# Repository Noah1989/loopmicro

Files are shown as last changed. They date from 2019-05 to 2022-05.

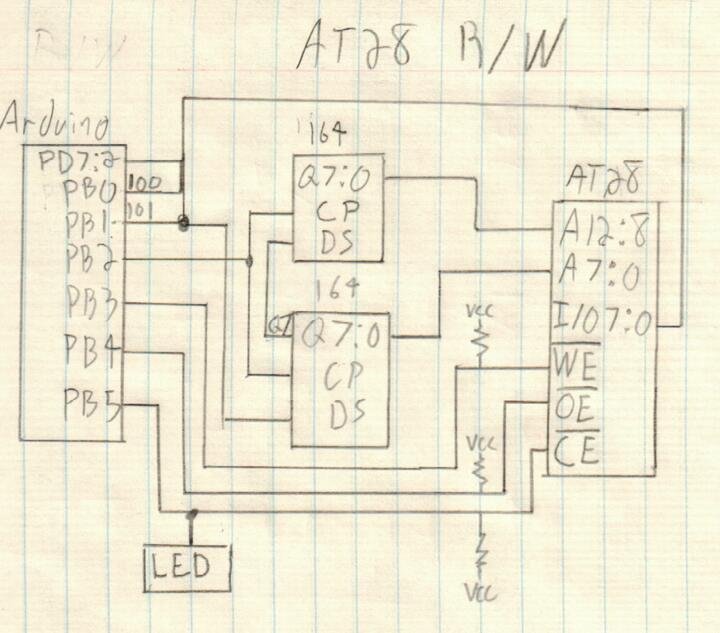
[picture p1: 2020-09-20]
software/collapseos/doc/hw/arduinouno/img/at28wr.jpg

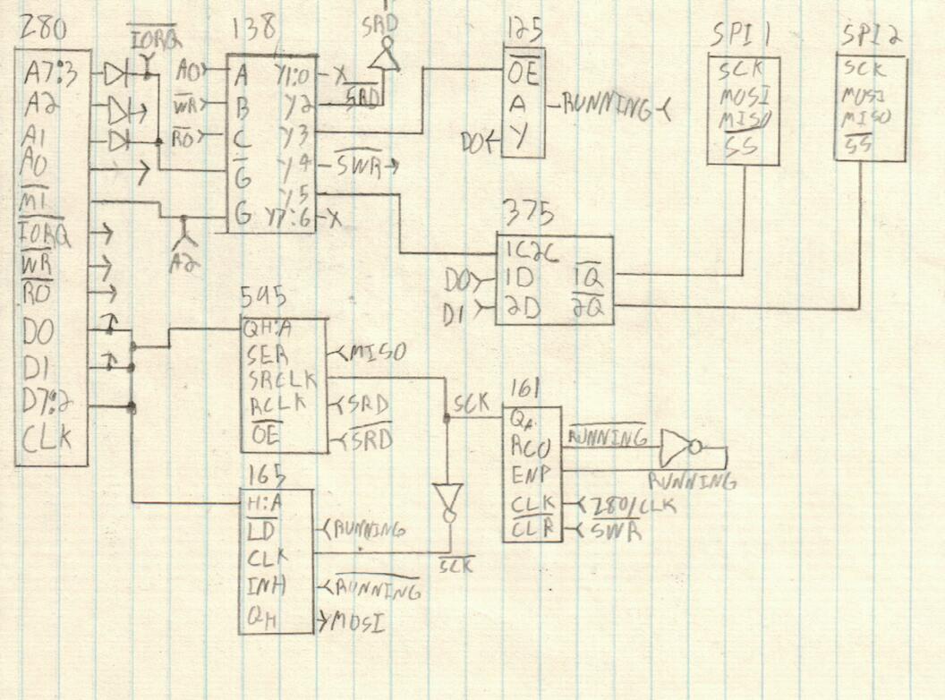
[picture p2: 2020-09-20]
software/collapseos/doc/hw/z80/img/spirelay.jpg

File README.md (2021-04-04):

# Loop Microcomputer
a minmal 8-bit machine that is...

- ... independent:
    - contains all the tools required to design another version of itself
    - does not require high soldering skills, uses through-hole parts only
    - uses only "evergreen" parts that have been in production for decades and are still made today

- ... aproachable:
    - simple through reduction
    - NO hidden complexity behind brittle abstractions
    - open source and self-documenting

- ... powerful, with it you can:
    - learn/teach how computers work
    - design electronics
    - control CNC machines / 3d printers
    - play games

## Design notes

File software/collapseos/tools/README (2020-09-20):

# Tools

This folder contains tools to communicate to Collapse OS machines from a modern
environment or to manipulate a blkfs. 

Communication tools all take a device path as a first argument. That device is
the serial device that connects you to your machine. It's often a USB-to-TTL
dongle. When `-` is specified, `stdin` is used as the device.

Note that for these tools to work well, you need the serial device to be
properly set up, TTY-wise. You'll probably want to do that with `stty`. The
recommended settings are "raw crtscts". Here's an example working on OpenBSD:

    $ ( stty 115200 raw crtscts ; ./upload - a000 os.bin ) <> /dev/cuaU0

To be honest, I'm having a bit of troubles making these tools work as well on
OpenBSD as they do in Linux. But it *does* work. Here are some advices:

* Use `cuaXX` instead of `ttyXX`.
* Run `cu -l /dev/cuaXX` before running your tool and run a dummy command to
  make sure that the output buffer is flushed.
* Use the "raw" option to avoid TTY-processing options to mess with data.
* If you experience random failures in your command, try inserting a "sleep 2"
  between your "stty" invocation and the command. In my experience, these tend
  to help.

On Linux, it's generally easier:

* Run screen on the device (often `/dev/ttyUSBX`)
* Quit with `CTRL+A :quit`
* Run the tool on the same device

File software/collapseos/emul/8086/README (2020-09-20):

# 8086 emulator

This folder contains emulator for 8086 binaries of Collapse OS. The bulk of
it is a fork of Fake86 by Mike Chambers.

`forth` is an imaginary hardware used for userspace development and testing.
This machine has an imaginary interrupt API and does not conform to PC/AT.

`pcat` is a very simple PC/AT emulator. The BIOS interrupt hooks implemented in
it only cover Collapse OS' own needs.

## Requirements

You need `curses` to build the `forth` executable.

## Build

Run `make` and it builds the `forth` and `pcat` interpreters.

## Usage

The `./forth` executable here works like the one in `/cvm`, except that it runs
under an emulated 8086 machine instead of running natively. Refer to
`/cvm/README` for details.

`pcat` needs to be suppied a path to a floppy disk image with a proper MBR.
`disk.bin` provided by the `pcat` recipe is sufficient.

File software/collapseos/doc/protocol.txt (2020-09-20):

# Protocols

Some subsystems (and in the case of KEY and EMIT, the core) re-
quire drivers to implement certain words in a certain way. For
example, the core requires drivers to implement (key?) and
(emit) or else it won't know how to provide a console.

These protocols are described here.

# TTY protocol

(key?)     -- c? f Returns whether a key has been pressed and,
                   if it has, returns which key. When f is
                   false, c is *not* placed in the stack.
(emit)     c --    Spit a character on the console.

# PS/2 protocol

This protocol enables communication with a device that spits
PS/2 keycodes.

(ps2kc)   -- kc    Returns the next typed PS/2 keycode from the
                   console. 0 if nothing was typed.

# SPI Relay protocol

This protocol enables communication with a SPI relay. This
protocol is designed to support devices with multiple endpoints.
To that end, (spie) takes a device ID argument, with a meaning
that is up to the device itself. To disable all devices, supply
0 to (spie).

We expect relay devices to support only one enabled device at
once. Enabling a specific device is expected to disable the
previously enabled one.

(spie)    n --     Enable SPI device
(spix)    n -- n   Perform SPI exchange (push a number, get a
                   number back)
                  
# Grid protocol

See grid.txt

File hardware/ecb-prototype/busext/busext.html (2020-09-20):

# /home/stefan/micro-21/hardware/ecb-prototype/busext/busext.sch

Sat May 8 12:38:23 2021

Eeschema 5.1.9

Component Count:13

Ref | Qnty | Value | Part | Footprint | Description | Vendor
C1, C2, C3, C4 | 4 | 100nF | Device:C_Small | Capacitor_THT:C_Rect_L7.2mm_W2.5mm_P5.00mm_FKS2_FKP2_MKS2_MKP2 | Unpolarized capacitor, small symbol
C5 | 1 | CP | Device:CP | Capacitor_THT:CP_Radial_D5.0mm_P2.00mm | Polarized capacitor
D1 | 1 | BAT46 | Device:D_Small_ALT | Diode_THT:D_DO-35_SOD27_P7.62mm_Horizontal | Diode, small symbol, filled shape
J1, J2 | 2 | C96ABC | Connector:C96ABC | Connector_DIN:DIN41612_C_3x32_Male_Horizontal_THT | Connector Europe, 96 contacts, ranges A,B,C
R1 | 1 | 10k | Device:R | Resistor_THT:R_Axial_DIN0207_L6.3mm_D2.5mm_P10.16mm_Horizontal | Resistor
U1, U2, U3 | 3 | 74HC244 | 74xx:74HC244 | Package_DIP:DIP-20_W7.62mm_Socket_LongPads | 8-bit Buffer/Line Driver 3-state
U4 | 1 | 74HC245 | 74xx:74HC245 | Package_DIP:DIP-20_W7.62mm_Socket_LongPads | Octal BUS Transceivers, 3-State outputs

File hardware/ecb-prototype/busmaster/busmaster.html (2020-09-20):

# /home/stefan/micro-21/hardware/ecb-prototype/busmaster/busmaster.sch

Sat May 8 12:36:06 2021

Eeschema 5.1.9

Component Count:33

Ref | Qnty | Value | Part | Footprint | Description | Vendor
C1, C2, C3, C4, C5, C6, C7, C8, C9, C10, C11, C12 | 12 | 100nF | Device:C_Small | Capacitor_THT:C_Rect_L7.2mm_W2.5mm_P5.00mm_FKS2_FKP2_MKS2_MKP2 | Unpolarized capacitor, small symbol
C13 | 1 | CP | Device:CP | Capacitor_THT:CP_Radial_D5.0mm_P2.00mm | Polarized capacitor
D1 | 1 | BAT46 | Device:D_Small_ALT | Diode_THT:D_DO-35_SOD27_P7.62mm_Horizontal | Diode, small symbol, filled shape
J1, J2 | 2 | C96ABC | Connector:C96ABC | Connector_DIN:DIN41612_C_3x32_Male_Horizontal_THT | Connector Europe, 96 contacts, ranges A,B,C
R1, R2, R3, R4 | 4 | R | Device:R | Resistor_THT:R_Axial_DIN0207_L6.3mm_D2.5mm_P10.16mm_Horizontal | Resistor
SW1 | 1 | SW_Coded_SH-7050 | Switch:SW_Coded_SH-7050 | Button_Switch_THT:Nidec_Copal_SH-7010C | Rotary switch, 4-bit encoding, 16 positions, Real code
U1 | 1 | 74HC688 | 74xx:74HC688 | Package_DIP:DIP-20_W7.62mm_Socket_LongPads | 8-bit magnitude comparator
U2 | 1 | 74HC138 | 74xx:74LS138 | Package_DIP:DIP-16_W7.62mm_Socket_LongPads | Decoder 3 to 8 active low outputs
U3 | 1 | 74HC00 | 74xx:7400 | Package_DIP:DIP-14_W7.62mm_Socket_LongPads | quad 2-input NAND gate
U4 | 1 | 74HC573 | 74xx:74LS573 | Package_DIP:DIP-20_W7.62mm_Socket_LongPads | 8-bit Latch 3-state outputs
U5, U10, U11 | 3 | 74HC244 | 74xx:74HC244 | Package_DIP:DIP-20_W7.62mm_Socket_LongPads | 8-bit Buffer/Line Driver 3-state
U6, U7, U8, U9 | 4 | 74HC161 | 74xx:74LS161 | Package_DIP:DIP-16_W7.62mm_Socket_LongPads | Synchronous 4-bit programmable binary Counter
U12 | 1 | 74HC245 | 74xx:74HC245 | Package_DIP:DIP-20_W7.62mm_Socket_LongPads | Octal BUS Transceivers, 3-State outputs

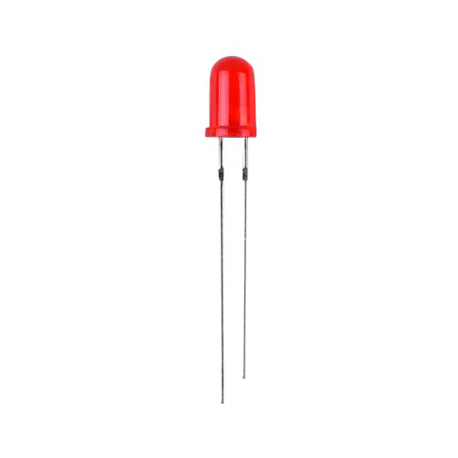
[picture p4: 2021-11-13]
emulator/assets/led.png

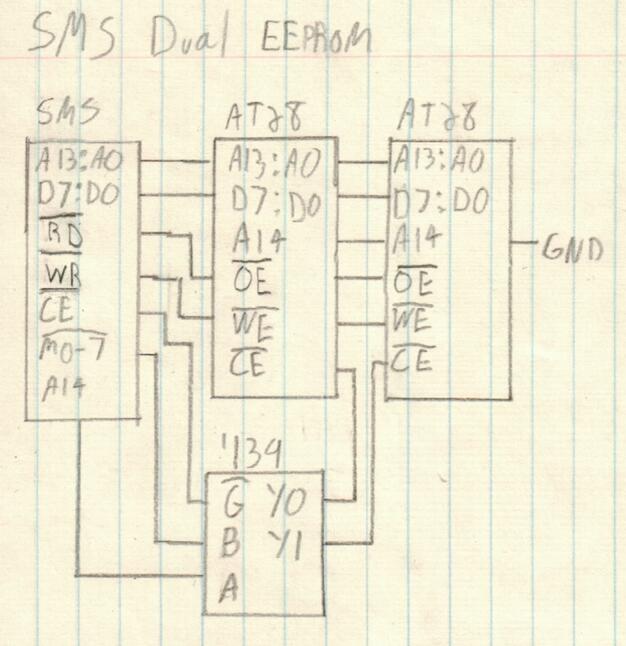
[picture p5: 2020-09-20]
software/collapseos/doc/hw/z80/sms/img/dual-at28.jpg

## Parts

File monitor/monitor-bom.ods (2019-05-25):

Designator | Package | Quantity | Designation
C2 | C_Rect_L7.2mm_W3.0mm_P5.00mm_FKS2_FKP2_MKS2_MKP2 | 1 | 0.1µF
C1 | CP_Radial_D5.0mm_P2.00mm | 1 | 1µF
D1,D2 | D_DO-35_SOD27_P7.62mm_Horizontal | 2 | DIODE
U1,U5 | DIP-14_W7.62mm_Socket_LongPads | 2 | 74HC4075
U3,U4 | DIP-14_W7.62mm_Socket_LongPads | 2 | 74HC00
U11 | DIP-14_W7.62mm_Socket_LongPads | 1 | 74HC08
U12 | DIP-14_W7.62mm_Socket_LongPads | 1 | 74HC86
U13 | DIP-14_W7.62mm_Socket_LongPads | 1 | 74HC74
U26,U27,U28,U29 | DIP-14_W7.62mm_Socket_LongPads | 4 | 74HC14
U2 | DIP-16_W7.62mm_Socket_LongPads | 1 | 74AC138
U8,U9,U10 | DIP-16_W7.62mm_Socket_LongPads | 3 | 74HC148
U6,U7 | DIP-20_W7.62mm_Socket_LongPads | 2 | 74AC574
U14,U16,U18,U20,U22,U24 | DIP-20_W7.62mm_Socket_LongPads | 6 | 74AC573
RN1,RN2,RN3 | R_Array_SIP9 | 3 | 220kΩ
R1 – R48 | R_Axial_DIN0204_L3.6mm_D1.6mm_P5.08mm_Horizontal | 48 | 220Ω
U15,U17,U19,U21,U23,U25 | SC39-11 | 6 | SC39-11
CN1,CN2,CN3 | SIP9_Housing | 3 | 0.1µF
J1 | Socket_DIN41612-CaseC1-full-Male-96Pin-3rows | 1 | C96ABC
SW1 – SW24 | SW_PUSH_6mm_h5mm | 24 | SW

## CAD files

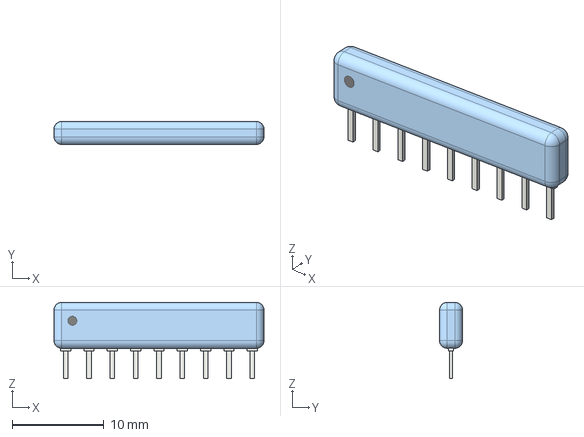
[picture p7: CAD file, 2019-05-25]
monitor/SIP9.STEP
22.9 x 2.51 x 8.30 mm

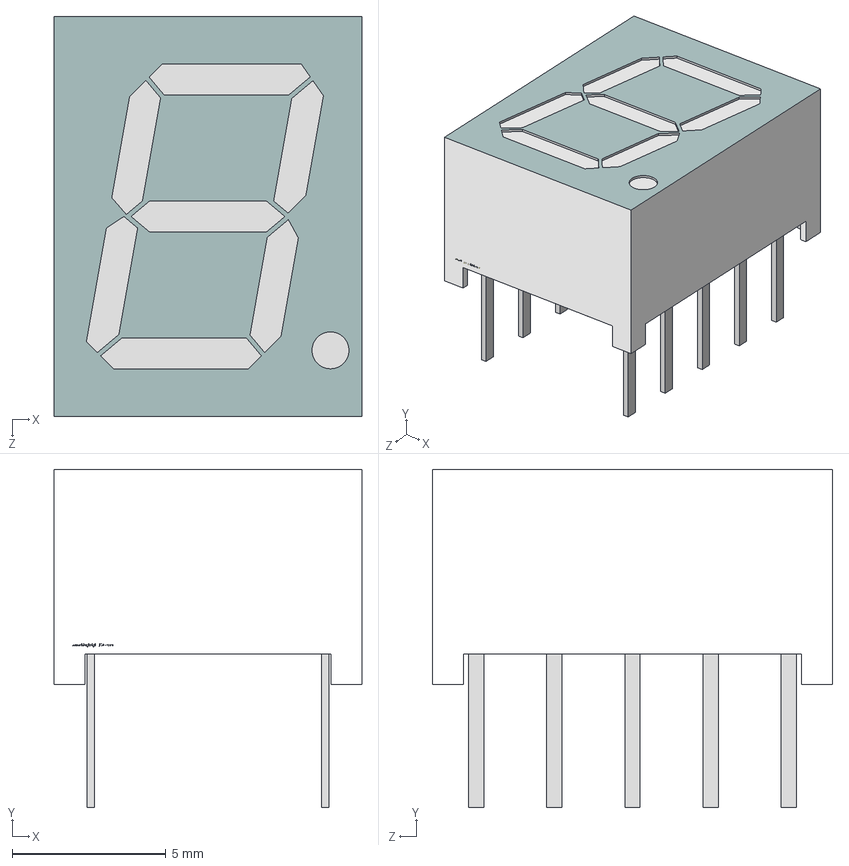
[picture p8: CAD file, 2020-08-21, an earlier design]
hardware/ecb-prototype/deprecated/monitor/SA39-11.STEP
10.0 x 11.0 x 13.0 mm

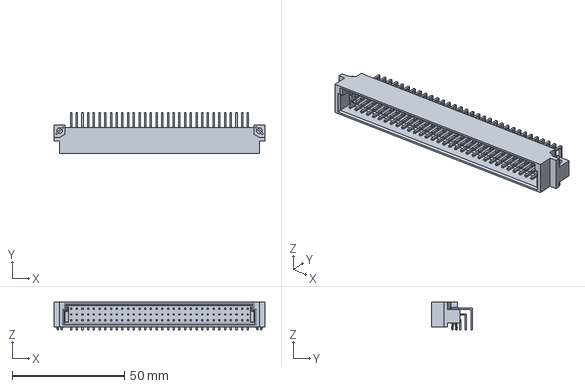
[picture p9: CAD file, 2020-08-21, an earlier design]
hardware/ecb-prototype/deprecated/monitor/850030567.stp
94.0 x 18.1 x 12.4 mm

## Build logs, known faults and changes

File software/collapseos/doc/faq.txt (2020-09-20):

# Frequently asked questions

# What is the easiest way to run Collapse OS on a modern
  computer?

Run the C VM in folder "/cvm". Run "make", then "./forth".
See doc/usage.txt for the rest.

# How do I use the different emulators?

Ah, you've noticed that /emul contains quite a few emulators.
Code in this folder only build emulators, not the binary to run
under it. It's the /arch folder that contains the makefiles to
build Collapse OS binaries to run under those.

When a binary built in /arch has a corresponding emulator, the
makefile has a "emul" target that you can use.

For example, "cd arch/z80/rc2014 && make emul" builds RC2014's
Collapse OS, the RC2014 emulator and then invokes the emulator.

# How do I fill my SD card with Collapse OS' FS?

Very easy. You see that "/cvm/blkfs" file? You dump it to your
raw device.  For example, if the device you get when you insert
your SD card is "/dev/sdb", then you type "cat emul/blkfs | sudo
tee /dev/sdb > /dev/null".

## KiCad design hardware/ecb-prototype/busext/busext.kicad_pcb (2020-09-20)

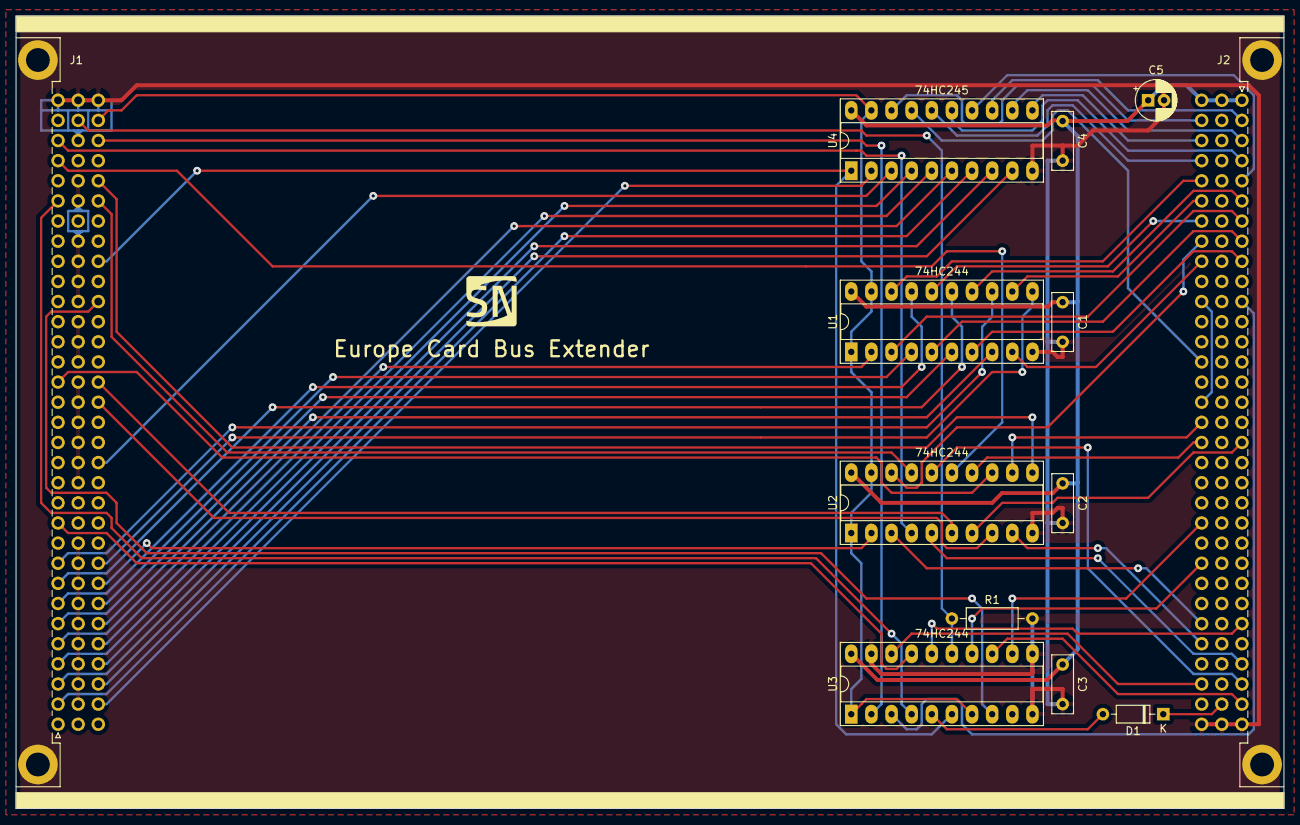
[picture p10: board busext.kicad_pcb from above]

Board: 2 copper layers, 160.0 x 100.0 mm, 13 parts (0 on the bottom side), 66 nets.

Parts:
C1, C2, C3, C4: 100nF; C_Rect_L7.2mm_W2.5mm_P5.00mm_FKS2_FKP2_MKS2_MKP2
C5: CP; CP_Radial_D5.0mm_P2.00mm
D1: BAT46; D_DO-35_SOD27_P7.62mm_Horizontal
J1, J2: C96ABC; DIN41612_C_3x32_Male_Horizontal_THT
R1: 10k; R_Axial_DIN0207_L6.3mm_D2.5mm_P10.16mm_Horizontal
U1, U2, U3: 74HC244; DIP-20_W7.62mm_Socket_LongPads
U4: 74HC245; DIP-20_W7.62mm_Socket_LongPads

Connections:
GND: C1.1, C2.1, C3.1, C4.1, C5.2, J1.A32, J1.B2, J1.B3, J1.B4, J1.B5, J1.B6, J1.B7, J1.B8, J1.B9, J1.B10, J1.B11, J1.B12, J1.B13, J1.B14, J1.B15, J1.B16, J1.B17, J1.B18, J1.B19, J1.B20, J1.B21, J1.B22, J1.B23, J1.B24, J1.B25, J1.B27, J1.B28, J1.B29, J1.B30, J1.B32, J1.C32, J2.A32, J2.B32, J2.C32, R1.2, U1.10, U2.10, U3.10, U3.11, U3.19, U4.10
MA0: J1.C5, U1.2
MA1: J1.C7, U1.4
MA2: J1.A6, U1.6
MA3: J1.C6, U1.8
MA4: J1.A7, U1.17
MA5: J1.A8, U1.15
MA6: J1.A9, U1.13
MA7: J1.C9, U1.11
MA8: J1.C8, U2.2
MA9: J1.A30, U2.4
MA10: J1.C18, U2.6
MA11: J1.C17, U2.8
MA12: J1.C27, U2.17
MA13: J1.A29, U2.15
MA14: J1.A18, U2.13
MA15: J1.C28, U2.11
MD0: J1.C2, U4.2
MD1: J1.C14, U4.3
MD2: J1.C4, U4.4
MD3: J1.A4, U4.5
MD4: J1.A5, U4.6
MD5: J1.A2, U4.7
MD6: J1.A3, U4.8
MD7: J1.C3, U4.9
MRESB: J1.B31, R1.1, U3.15
unnamed: D1.2, U3.5
unnamed: J2.C11, J2.C16
SA0: J2.C5, U1.18
SA1: J2.C7, U1.16
SA2: J2.A6, U1.14
SA3: J2.C6, U1.12
SA4: J2.A7, U1.3
SA5: J2.A8, U1.5
SA6: J2.A9, U1.7
SA7: J2.C9, U1.9
SA8: J2.C8, U2.18
SA9: J2.A30, U2.16
SA10: J2.C18, U2.14
SA11: J2.C17, U2.12
SA12: J2.C27, U2.3
SA13: J2.A29, U2.5
SA14: J2.A18, U2.7
SA15: J2.C28, U2.9
SD0: J2.C2, U4.18
SD1: J2.C14, U4.17
SD2: J2.C4, U4.16
SD3: J2.A4, U4.15
SD4: J2.A5, U4.14
SD5: J2.A2, U4.13
SD6: J2.A3, U4.12
SD7: J2.C3, U4.11
SRESB: D1.1, J2.B31
VCC: C1.2, C2.2, C3.2, C4.2, C5.1, J2.A1, J2.B1, J2.C1, U1.20, U2.20, U3.20, U4.20
~BUSACK: J1.C31, U1.1, U1.19, U2.1, U2.19, U3.1, U3.7, U4.19
~MBUSRQ: J1.A11, U3.17
~MIORQ: J1.A27, U3.4
~MMREQ: J1.C30, U3.2
~MRD: J1.C24, U3.6, U4.1
~MWR: J1.C22, U3.8
~SBUSACK: J2.A31, U3.13
~SBUSRQ: J2.A11, U3.3
~SIORQ: J2.A27, U3.16
~SMREQ: J2.C30, U3.18
~SRD: J2.C24, U3.14
~SWR: J2.C22, U3.12

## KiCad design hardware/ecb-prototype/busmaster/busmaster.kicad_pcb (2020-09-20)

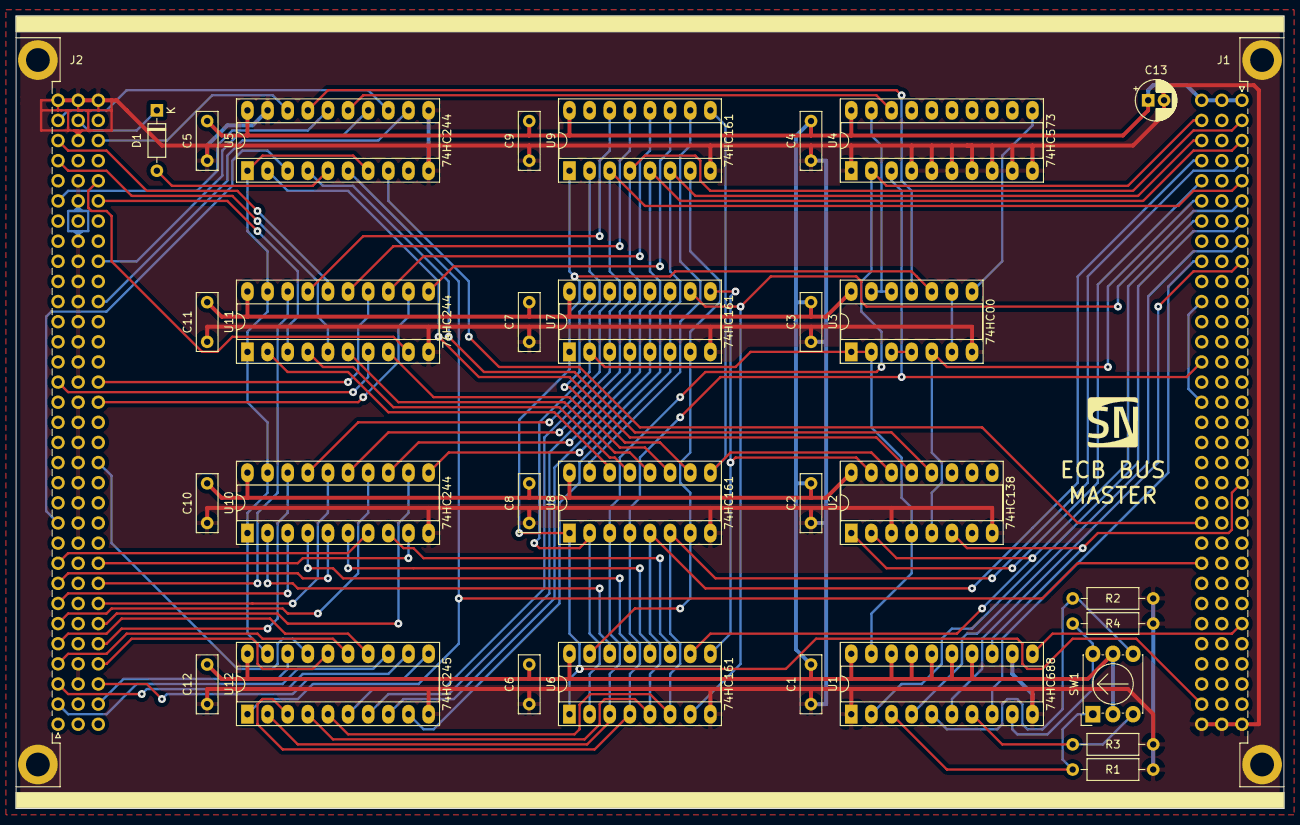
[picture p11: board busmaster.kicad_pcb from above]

Board: 2 copper layers, 160.0 x 100.0 mm, 33 parts (0 on the bottom side), 91 nets.

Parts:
C1, C2, C3, C4, C5, C6, C7, C8, C9, C10, C11, C12: 100nF; C_Rect_L7.2mm_W2.5mm_P5.00mm_FKS2_FKP2_MKS2_MKP2
C13: CP; CP_Radial_D5.0mm_P2.00mm
D1: BAT46; D_DO-35_SOD27_P7.62mm_Horizontal
J1, J2: C96ABC; DIN41612_C_3x32_Male_Horizontal_THT
R1, R2, R3, R4: R; R_Axial_DIN0207_L6.3mm_D2.5mm_P10.16mm_Horizontal
SW1: SW_Coded_SH-7050; Nidec_Copal_SH-7010C
U1: 74HC688; DIP-20_W7.62mm_Socket_LongPads
U2: 74HC138; DIP-16_W7.62mm_Socket_LongPads
U3: 74HC00; DIP-14_W7.62mm_Socket_LongPads
U4: 74HC573; DIP-20_W7.62mm_Socket_LongPads
U5, U10, U11: 74HC244; DIP-20_W7.62mm_Socket_LongPads
U6, U7, U8, U9: 74HC161; DIP-16_W7.62mm_Socket_LongPads
U12: 74HC245; DIP-20_W7.62mm_Socket_LongPads

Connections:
GND: C1.1, C2.1, C3.1, C4.1, C5.1, C6.1, C7.1, C8.1, C9.1, C10.1, C11.1, C12.1, C13.2, J1.A32, J1.B32, J1.C32, J2.A32, J2.B2, J2.B3, J2.B4, J2.B5, J2.B6, J2.B7, J2.B8, J2.B9, J2.B10, J2.B11, J2.B12, J2.B13, J2.B14, J2.B15, J2.B16, J2.B17, J2.B18, J2.B19, J2.B20, J2.B21, J2.B22, J2.B23, J2.B24, J2.B25, J2.B27, J2.B28, J2.B29, J2.B30, J2.B32, J2.C32, R1.2, R2.2, R3.2, R4.2, U1.1, U1.10, U1.12, U2.3, U2.8, U3.7, U4.1, U4.4, U4.5, U4.6, U4.7, U4.8, U4.9, U4.10, U5.10, U5.11, U5.19, U6.8, U7.8, U8.8, U9.8, U10.10, U11.10, U12.10
MA0: J1.C5, U2.1
MA1: J1.C7, U2.2, U6.10
MA2: J1.A6, U6.7, U7.10
MA3: J1.C6, U2.5, U3.5
MA4: J1.A7, U1.2
MA5: J1.A8, U1.4
MA6: J1.A9, U1.6
MA7: J1.C9, U1.8
MD0: J1.C2, U4.2, U6.3, U8.3, U12.2
MD1: J1.C14, U4.3, U6.4, U8.4, U12.3
MD2: J1.C4, U6.5, U8.5, U12.4
MD3: J1.A4, U6.6, U8.6, U12.5
MD4: J1.A5, U7.3, U9.3, U12.6
MD5: J1.A2, U7.4, U9.4, U12.7
MD6: J1.A3, U7.5, U9.5, U12.8
MD7: J1.C3, U7.6, U9.6, U12.9
unnamed: D1.2, U5.5
unnamed: J1.C11, J1.C16
unnamed: R1.1, SW1.1, U1.3
unnamed: R2.1, SW1.2, U1.5
unnamed: R3.1, SW1.4, U1.7
unnamed: R4.1, SW1.8, U1.9
unnamed: U1.19, U2.4, U3.1, U3.2, U6.2, U7.2, U8.2, U9.2
unnamed: U2.12, U5.4
unnamed: U2.13, U5.2
unnamed: U2.14, U8.9, U9.9
unnamed: U2.15, U6.9, U7.9
unnamed: U3.3, U3.4
unnamed: U3.6, U3.9
unnamed: U3.8, U4.11
unnamed: U3.11, U5.17
unnamed: U3.12, U3.13, U4.19
unnamed: U4.18, U5.15
unnamed: U6.15, U7.7, U8.7, U9.7
unnamed: U7.15, U8.10
unnamed: U8.15, U9.10
unnamed: U6.14, U10.2
unnamed: U6.13, U10.4
unnamed: U6.12, U10.6
unnamed: U6.11, U10.8
unnamed: U7.11, U10.11
unnamed: U7.12, U10.13
unnamed: U7.13, U10.15
unnamed: U7.14, U10.17
unnamed: U8.14, U11.2
unnamed: U8.13, U11.4
unnamed: U8.12, U11.6
unnamed: U8.11, U11.8
unnamed: U9.11, U11.11
unnamed: U9.12, U11.13
unnamed: U9.13, U11.15
unnamed: U9.14, U11.17
SA0: J2.C5, U10.18
SA1: J2.C7, U10.16
SA2: J2.A6, U10.14
SA3: J2.C6, U10.12
SA4: J2.A7, U10.3
SA5: J2.A8, U10.5
SA6: J2.A9, U10.7
SA7: J2.C9, U10.9
SA8: J2.C8, U11.18
SA9: J2.A30, U11.16
SA10: J2.C18, U11.14
SA11: J2.C17, U11.12
SA12: J2.C27, U11.3
SA13: J2.A29, U11.5
SA14: J2.A18, U11.7
SA15: J2.C28, U11.9
SD0: J2.C2, U12.18
SD1: J2.C14, U12.17
SD2: J2.C4, U12.16
SD3: J2.A4, U12.15
SD4: J2.A5, U12.14
SD5: J2.A2, U12.13
SD6: J2.A3, U12.12
SD7: J2.C3, U12.11
SRESB: D1.1, J2.B31
VCC: C1.2, C2.2, C3.2, C4.2, C5.2, C6.2, C7.2, C8.2, C9.2, C10.2, C11.2, C12.2, C13.1, J1.A1, J1.B1, J1.C1, SW1.C, U1.14, U1.15, U1.16, U1.17, U1.18, U1.20, U2.16, U3.14, U4.20, U5.20, U6.16, U7.16, U8.16, U9.16, U10.20, U11.20, U12.20
~BUSACK: U5.1, U5.7, U10.1, U10.19, U11.1, U11.19, U12.19
~MIORQ: J1.A27, U1.11
~MM1: J1.A20, U1.13, U2.6
~MRD: J1.C24, U5.6, U12.1
~MRESET: J1.C31, U3.10, U6.1, U7.1, U8.1, U9.1
~MWR: J1.C22, U5.8
~SBUSACK: J2.A31, U5.13
~SBUSRQ: J2.A11, U5.3
~SIORQ: J2.A27, U5.16
~SMREQ: J2.C30, U5.18
~SRD: J2.C24, U5.14
~SWR: J2.C22, U5.12

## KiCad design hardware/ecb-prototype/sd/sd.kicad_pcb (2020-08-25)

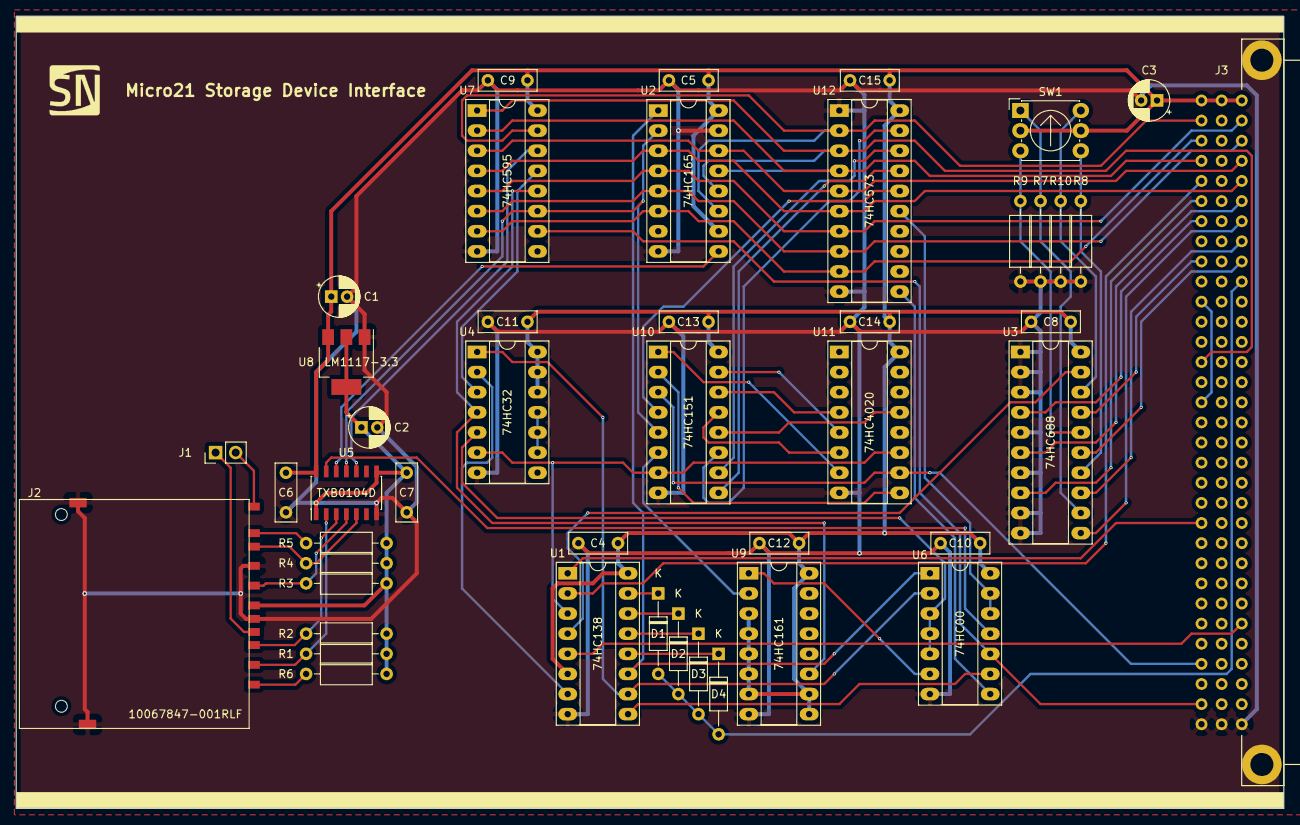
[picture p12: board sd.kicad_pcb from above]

Board: 2 copper layers, 160.0 x 100.0 mm, 45 parts (0 on the bottom side), 69 nets.

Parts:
C1, C2, C3: CP_Small; CP_Radial_D5.0mm_P2.00mm
C4, C5, C6, C7, C8, C9, C10, C11, C12, C13, C14, C15: C; C_Rect_L7.2mm_W2.5mm_P5.00mm_FKS2_FKP2_MKS2_MKP2
D1, D2, D3, D4: BAT46; D_DO-35_SOD27_P10.16mm_Horizontal
J1: Conn_01x02_Male; PinHeader_1x02_P2.54mm_Vertical
J2: 10067847-001RLF; 10067847
J3: C96ABC; Socket_DIN41612-CaseC1-full-Male-96Pin-3rows
R1, R2, R3, R4, R5, R6, R7, R8, R9, R10: 100k; R_Axial_DIN0207_L6.3mm_D2.5mm_P10.16mm_Horizontal
SW1: SW_Coded_SH-7050; Nidec_Copal_SH-7010C
U1: 74HC138; DIP-16_W7.62mm_Socket_LongPads
U2: 74HC165; DIP-16_W7.62mm_Socket_LongPads
U3: 74HC688; DIP-20_W7.62mm_Socket_LongPads
U4: 74HC32; DIP-14_W7.62mm_Socket_LongPads
U5: TXB0104D; SOIC-14_3.9x8.7mm_P1.27mm
U6: 74HC00; DIP-14_W7.62mm_Socket_LongPads
U7: 74HC595; DIP-16_W7.62mm_Socket_LongPads
U8: LM1117-3.3; SOT-223-3_TabPin2
U9: 74HC161; DIP-16_W7.62mm_Socket_LongPads
U10: 74HC151; DIP-16_W7.62mm_Socket_LongPads
U11: 74HC4020; DIP-16_W7.62mm_Socket_LongPads
U12: 74HC573; DIP-20_W7.62mm_Socket_LongPads

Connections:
+3V3: C2.1, C7.1, J2.4, R1.1, R2.1, R3.1, R4.1, R5.1, R6.1, U5.1, U5.8, U8.2
+5V: C1.1, C3.1, C4.1, C5.1, C6.1, C8.1, C9.1, C10.1, C11.1, C12.1, C13.1, C14.1, C15.1, J3.A1, J3.B1, J3.C1, SW1.C, U1.6, U1.16, U2.10, U2.16, U3.20, U4.12, U4.13, U4.14, U5.14, U6.14, U7.16, U8.3, U9.3, U9.4, U9.5, U9.6, U9.7, U9.9, U9.10, U9.16, U10.16, U11.16, U12.20
/CS: J2.1, R1.2, U5.2
/DI: J2.2, R2.2, U5.3
/DO: J2.7, R4.2, U5.5
/SCLK: J2.5, R3.2, U5.4
A0: J3.C5, U1.2
A1: J3.C7, U3.4
A2: J3.A6, U3.6
A3: J3.C6, U3.8
A4: J3.A7, U3.11
A5: J3.A8, U3.13
A6: J3.A9, U3.15
A7: J3.C9, U3.17
CLK: J3.C29, U10.3, U11.10
D0: J3.C2, U2.11, U7.15, U12.2
D1: J3.C14, U2.12, U7.1, U12.3
D2: J3.C4, U2.13, U7.2, U12.4
D3: J3.A4, U2.14, U7.3, U12.5
D4: J3.A5, U2.3, U7.4, U12.6
D5: J3.A2, U2.4, U7.5, U12.7
D6: J3.A3, U2.5, U7.6, U12.8
D7: J3.C3, U2.6, U7.7, U12.9
GND: C1.2, C2.2, C3.2, C4.2, C5.2, C6.2, C7.2, C8.2, C9.2, C10.2, C11.2, C12.2, C13.2, C14.2, C15.2, J2.3, J2.6, J2.12, J2.13, J3.A32, J3.B32, J3.C32, R7.2, R8.2, R9.2, R10.2, U1.8, U2.8, U2.15, U3.1, U3.2, U3.3, U3.5, U3.7, U3.9, U3.10, U4.7, U5.7, U6.7, U7.8, U8.1, U9.8, U10.8, U11.8, U12.1, U12.10
unnamed: D1.1, U1.15
unnamed: D2.1, U1.14
unnamed: D3.1, U1.13
unnamed: D4.1, U1.12
unnamed: J1.1, J2.10
unnamed: J1.2, J2.11
unnamed: J2.8, R5.2
unnamed: J2.9, R6.2
unnamed: J3.C11, J3.C16
unnamed: R7.1, SW1.1, U3.12
unnamed: R8.1, SW1.2, U3.14
unnamed: R9.1, SW1.4, U3.16
unnamed: R10.1, SW1.8, U3.18
unnamed: U1.3, U4.6, U10.7, U11.11
unnamed: U1.4, U3.19
unnamed: U1.7, U4.2
unnamed: U1.9, U6.9
unnamed: U1.10, U4.1, U6.2
unnamed: U1.11, U2.1, U6.1
unnamed: U2.9, U5.12
unnamed: U4.3, U7.13
unnamed: U4.4, U7.12, U9.11
unnamed: U4.5, U6.3, U6.4, U6.5
unnamed: U4.9, U4.10, U4.11
unnamed: U5.10, U7.14
unnamed: U5.13, U6.11
unnamed: U6.6, U9.1
unnamed: U10.1, U11.7
unnamed: U10.2, U11.9
unnamed: U10.4, U12.16
unnamed: U2.2, U5.11, U7.11, U10.5
unnamed: U9.2, U10.6
unnamed: U10.9, U12.17
unnamed: U10.10, U12.18
unnamed: U10.11, U12.19
unnamed: U10.12, U11.13
unnamed: U10.13, U11.6
unnamed: U10.14, U11.4
unnamed: U10.15, U11.5
unnamed: U6.8, U12.11
unnamed: U6.12, U6.13, U12.15
~IORQ: J3.A27, U1.5
~RESET: J3.C31, U6.10, U7.10
~WAIT: D1.2, D2.2, D3.2, D4.2, J3.A10
~WR: J3.C22, U1.1

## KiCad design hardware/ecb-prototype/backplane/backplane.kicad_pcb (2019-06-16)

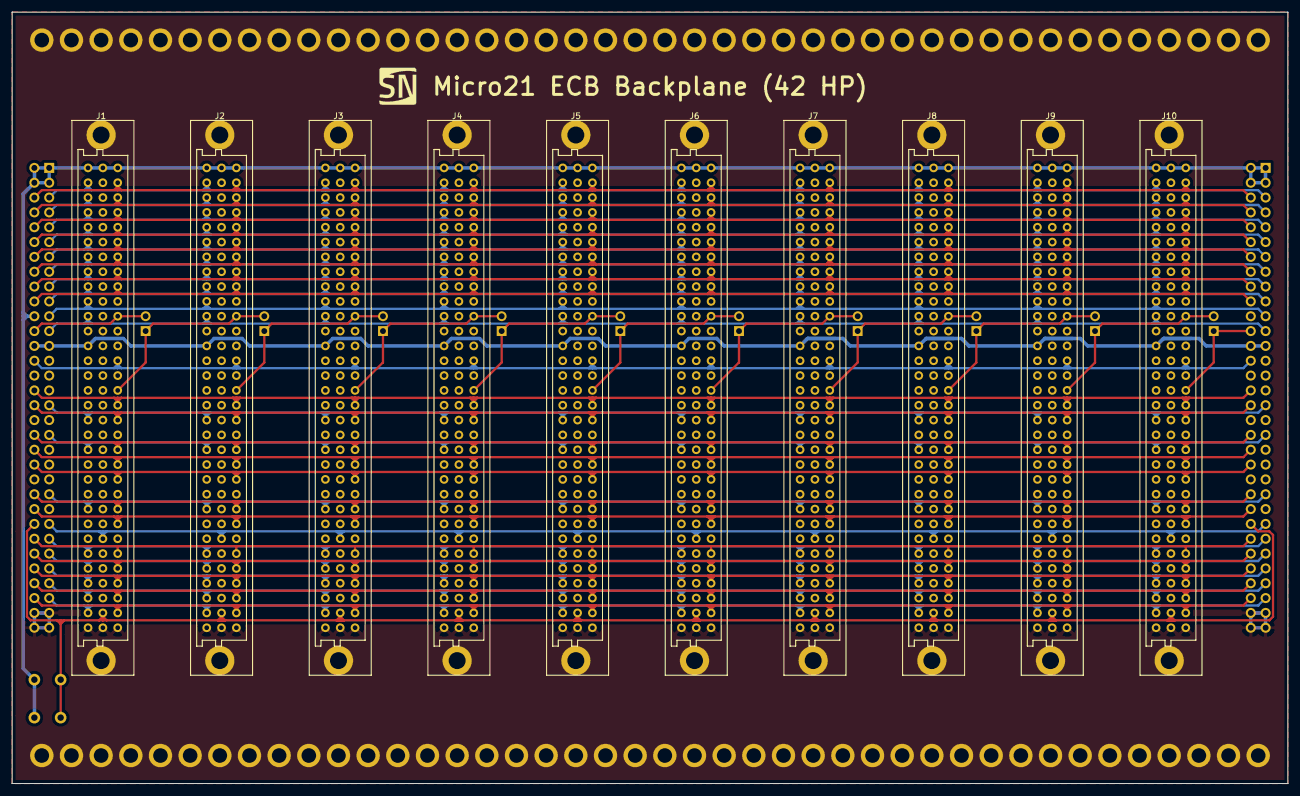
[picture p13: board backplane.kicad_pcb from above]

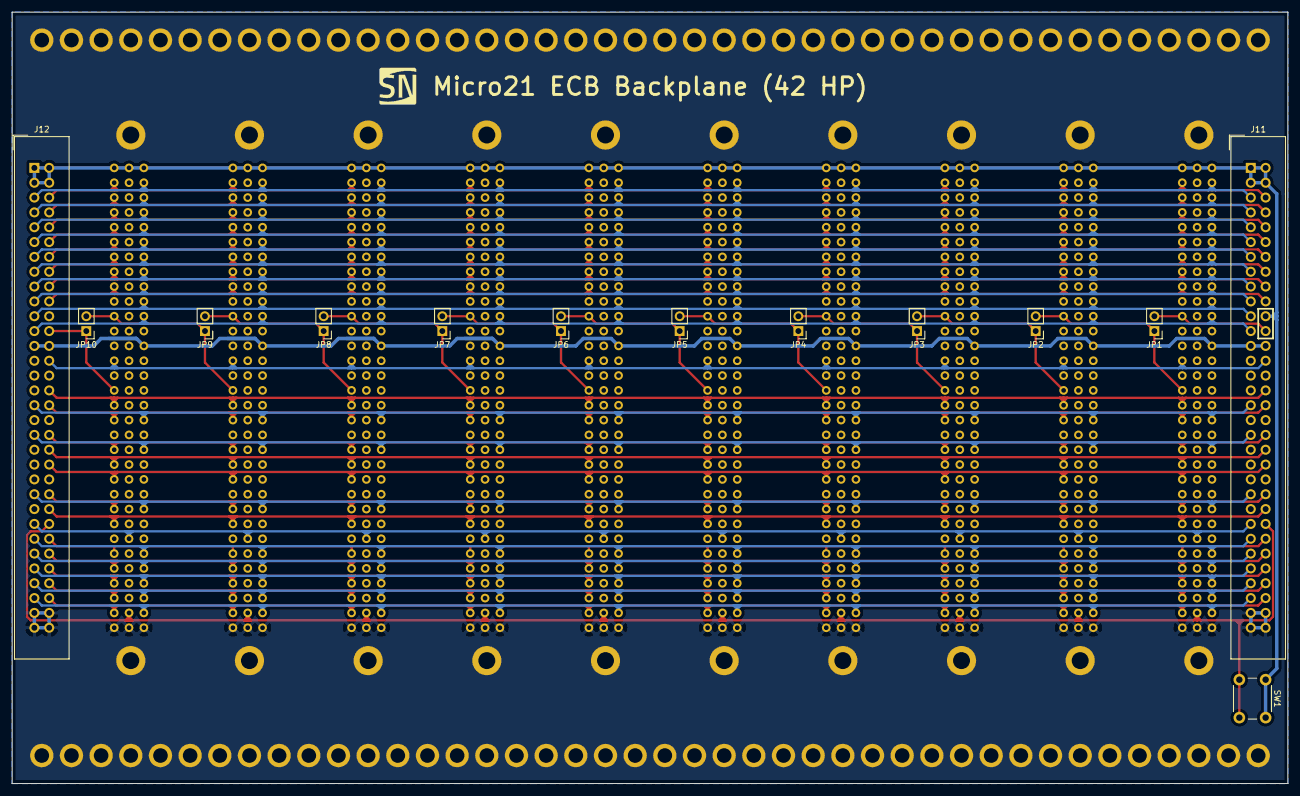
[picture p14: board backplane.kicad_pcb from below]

Board: 2 copper layers, 218.4 x 132.1 mm, 23 parts (13 on the bottom side), 55 nets.

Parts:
J1, J2, J3, J4, J5, J6, J7, J8, J9, J10: C96ABC; Socket_DIN41612-CaseC1-full-Female-96Pin-3rows
J11, J12: Conn_02x32_Odd_Even; IDC-Header_2x32_P2.54mm_Vertical
JP1, JP2, JP3, JP4, JP5, JP6, JP7, JP8, JP9, JP10: Jumper; PinHeader_1x02_P2.54mm_Vertical
SW1: SW_Push; SW_PUSH_6mm_H7.3mm

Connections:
+12V: J1.A13, J2.A13, J3.A13, J4.A13, J5.A13, J6.A13, J7.A13, J8.A13, J9.A13, J10.A13, J11.25, J11.26, J12.25, J12.26
+BATT: J1.A24, J2.A24, J3.A24, J4.A24, J5.A24, J6.A24, J7.A24, J8.A24, J9.A24, J10.A24, J11.45, J12.45
A0: J1.C5, J2.C5, J3.C5, J4.C5, J5.C5, J6.C5, J7.C5, J8.C5, J9.C5, J10.C5, J11.12, J12.12
A1: J1.C7, J2.C7, J3.C7, J4.C7, J5.C7, J6.C7, J7.C7, J8.C7, J9.C7, J10.C7, J11.16, J12.16
A2: J1.A6, J2.A6, J3.A6, J4.A6, J5.A6, J6.A6, J7.A6, J8.A6, J9.A6, J10.A6, J11.13, J12.13
A3: J1.C6, J2.C6, J3.C6, J4.C6, J5.C6, J6.C6, J7.C6, J8.C6, J9.C6, J10.C6, J11.14, J12.14
A4: J1.A7, J2.A7, J3.A7, J4.A7, J5.A7, J6.A7, J7.A7, J8.A7, J9.A7, J10.A7, J11.15, J12.15
A5: J1.A8, J2.A8, J3.A8, J4.A8, J5.A8, J6.A8, J7.A8, J8.A8, J9.A8, J10.A8, J11.17, J12.17
A6: J1.A9, J2.A9, J3.A9, J4.A9, J5.A9, J6.A9, J7.A9, J8.A9, J9.A9, J10.A9, J11.19, J12.19
A7: J1.C9, J2.C9, J3.C9, J4.C9, J5.C9, J6.C9, J7.C9, J8.C9, J9.C9, J10.C9, J11.20, J12.20
A8: J1.C8, J2.C8, J3.C8, J4.C8, J5.C8, J6.C8, J7.C8, J8.C8, J9.C8, J10.C8, J11.18, J12.18
A9: J1.A30, J2.A30, J3.A30, J4.A30, J5.A30, J6.A30, J7.A30, J8.A30, J9.A30, J10.A30, J11.57, J12.57
A10: J1.C18, J2.C18, J3.C18, J4.C18, J5.C18, J6.C18, J7.C18, J8.C18, J9.C18, J10.C18, J11.34, J12.34
A11: J1.C17, J2.C17, J3.C17, J4.C17, J5.C17, J6.C17, J7.C17, J8.C17, J9.C17, J10.C17, J11.32, J12.32
A12: J1.C27, J2.C27, J3.C27, J4.C27, J5.C27, J6.C27, J7.C27, J8.C27, J9.C27, J10.C27, J11.52, J12.52
A13: J1.A29, J2.A29, J3.A29, J4.A29, J5.A29, J6.A29, J7.A29, J8.A29, J9.A29, J10.A29, J11.55, J12.55
A14: J1.A18, J2.A18, J3.A18, J4.A18, J5.A18, J6.A18, J7.A18, J8.A18, J9.A18, J10.A18, J11.33, J12.33
A15: J1.C28, J2.C28, J3.C28, J4.C28, J5.C28, J6.C28, J7.C28, J8.C28, J9.C28, J10.C28, J11.54, J12.54
CLK: J1.C29, J2.C29, J3.C29, J4.C29, J5.C29, J6.C29, J7.C29, J8.C29, J9.C29, J10.C29, J11.56, J12.56
D0: J1.C2, J2.C2, J3.C2, J4.C2, J5.C2, J6.C2, J7.C2, J8.C2, J9.C2, J10.C2, J11.6, J12.6
D1: J1.C14, J2.C14, J3.C14, J4.C14, J5.C14, J6.C14, J7.C14, J8.C14, J9.C14, J10.C14, J11.28, J12.28
D2: J1.C4, J2.C4, J3.C4, J4.C4, J5.C4, J6.C4, J7.C4, J8.C4, J9.C4, J10.C4, J11.10, J12.10
D3: J1.A4, J2.A4, J3.A4, J4.A4, J5.A4, J6.A4, J7.A4, J8.A4, J9.A4, J10.A4, J11.9, J12.9
D4: J1.A5, J2.A5, J3.A5, J4.A5, J5.A5, J6.A5, J7.A5, J8.A5, J9.A5, J10.A5, J11.11, J12.11
D5: J1.A2, J2.A2, J3.A2, J4.A2, J5.A2, J6.A2, J7.A2, J8.A2, J9.A2, J10.A2, J11.5, J12.5
D6: J1.A3, J2.A3, J3.A3, J4.A3, J5.A3, J6.A3, J7.A3, J8.A3, J9.A3, J10.A3, J11.7, J12.7
D7: J1.C3, J2.C3, J3.C3, J4.C3, J5.C3, J6.C3, J7.C3, J8.C3, J9.C3, J10.C3, J11.8, J12.8
GND: J1.A32, J1.B32, J1.C32, J2.A32, J2.B32, J2.C32, J3.A32, J3.B32, J3.C32, J4.A32, J4.B32, J4.C32, J5.A32, J5.B32, J5.C32, J6.A32, J6.B32, J6.C32, J7.A32, J7.B32, J7.C32, J8.A32, J8.B32, J8.C32, J9.A32, J9.B32, J9.C32, J10.A32, J10.B32, J10.C32, J11.61, J11.62, J11.63, J11.64, J12.61, J12.62, J12.63, J12.64
unnamed: J1.C11, J11.24, JP1.2
unnamed: J1.C16, J2.C11, JP1.1, JP2.2
unnamed: J2.C16, J3.C11, JP2.1, JP3.2
unnamed: J3.C16, J4.C11, JP3.1, JP4.2
unnamed: J4.C16, J5.C11, JP4.1, JP5.2
unnamed: J5.C16, J6.C11, JP5.1, JP6.2
unnamed: J6.C16, J7.C11, JP6.1, JP7.2
unnamed: J7.C16, J8.C11, JP7.1, JP8.2
unnamed: J8.C16, J9.C11, JP8.1, JP9.2
unnamed: J9.C16, J10.C11, JP9.1, JP10.2
unnamed: J10.C16, J12.24, JP10.1
RESB: J1.B31, J2.B31, J3.B31, J4.B31, J5.B31, J6.B31, J7.B31, J8.B31, J9.B31, J10.B31, J11.50, J12.50, SW1.2
VCC: J1.A1, J1.B1, J1.C1, J2.A1, J2.B1, J2.C1, J3.A1, J3.B1, J3.C1, J4.A1, J4.B1, J4.C1, J5.A1, J5.B1, J5.C1, J6.A1, J6.B1, J6.C1, J7.A1, J7.B1, J7.C1, J8.A1, J8.B1, J8.C1, J9.A1, J9.B1, J9.C1, J10.A1, J10.B1, J10.C1, J11.1, J11.2, J11.3, J11.4, J11.22, J12.1, J12.2, J12.3, J12.4, SW1.1
~BUSAK: J1.A31, J2.A31, J3.A31, J4.A31, J5.A31, J6.A31, J7.A31, J8.A31, J9.A31, J10.A31, J11.59, J12.59
~BUSRQ: J1.A11, J2.A11, J3.A11, J4.A11, J5.A11, J6.A11, J7.A11, J8.A11, J9.A11, J10.A11, J11.23, J12.23
~HALT: J1.C25, J2.C25, J3.C25, J4.C25, J5.C25, J6.C25, J7.C25, J8.C25, J9.C25, J10.C25, J11.48, J12.48
~INT: J1.C21, J2.C21, J3.C21, J4.C21, J5.C21, J6.C21, J7.C21, J8.C21, J9.C21, J10.C21, J11.40, J12.40
~IORQ: J1.A27, J2.A27, J3.A27, J4.A27, J5.A27, J6.A27, J7.A27, J8.A27, J9.A27, J10.A27, J11.51, J12.51
~M1: J1.A20, J2.A20, J3.A20, J4.A20, J5.A20, J6.A20, J7.A20, J8.A20, J9.A20, J10.A20, J11.37, J12.37
~MREQ: J1.C30, J2.C30, J3.C30, J4.C30, J5.C30, J6.C30, J7.C30, J8.C30, J9.C30, J10.C30, J11.58, J12.58
~NMI: J1.C20, J2.C20, J3.C20, J4.C20, J5.C20, J6.C20, J7.C20, J8.C20, J9.C20, J10.C20, J11.38, J12.38
~RD: J1.C24, J2.C24, J3.C24, J4.C24, J5.C24, J6.C24, J7.C24, J8.C24, J9.C24, J10.C24, J11.46, J12.46
~RESET: J1.C31, J2.C31, J3.C31, J4.C31, J5.C31, J6.C31, J7.C31, J8.C31, J9.C31, J10.C31, J11.60, J12.60
~RFSH: J1.A28, J2.A28, J3.A28, J4.A28, J5.A28, J6.A28, J7.A28, J8.A28, J9.A28, J10.A28, J11.53, J12.53
~ROB: J1.B26, J2.B26, J3.B26, J4.B26, J5.B26, J6.B26, J7.B26, J8.B26, J9.B26, J10.B26, J11.49, J12.49
~WAIT: J1.A10, J2.A10, J3.A10, J4.A10, J5.A10, J6.A10, J7.A10, J8.A10, J9.A10, J10.A10, J11.21, J12.21
~WR: J1.C22, J2.C22, J3.C22, J4.C22, J5.C22, J6.C22, J7.C22, J8.C22, J9.C22, J10.C22, J11.42, J12.42

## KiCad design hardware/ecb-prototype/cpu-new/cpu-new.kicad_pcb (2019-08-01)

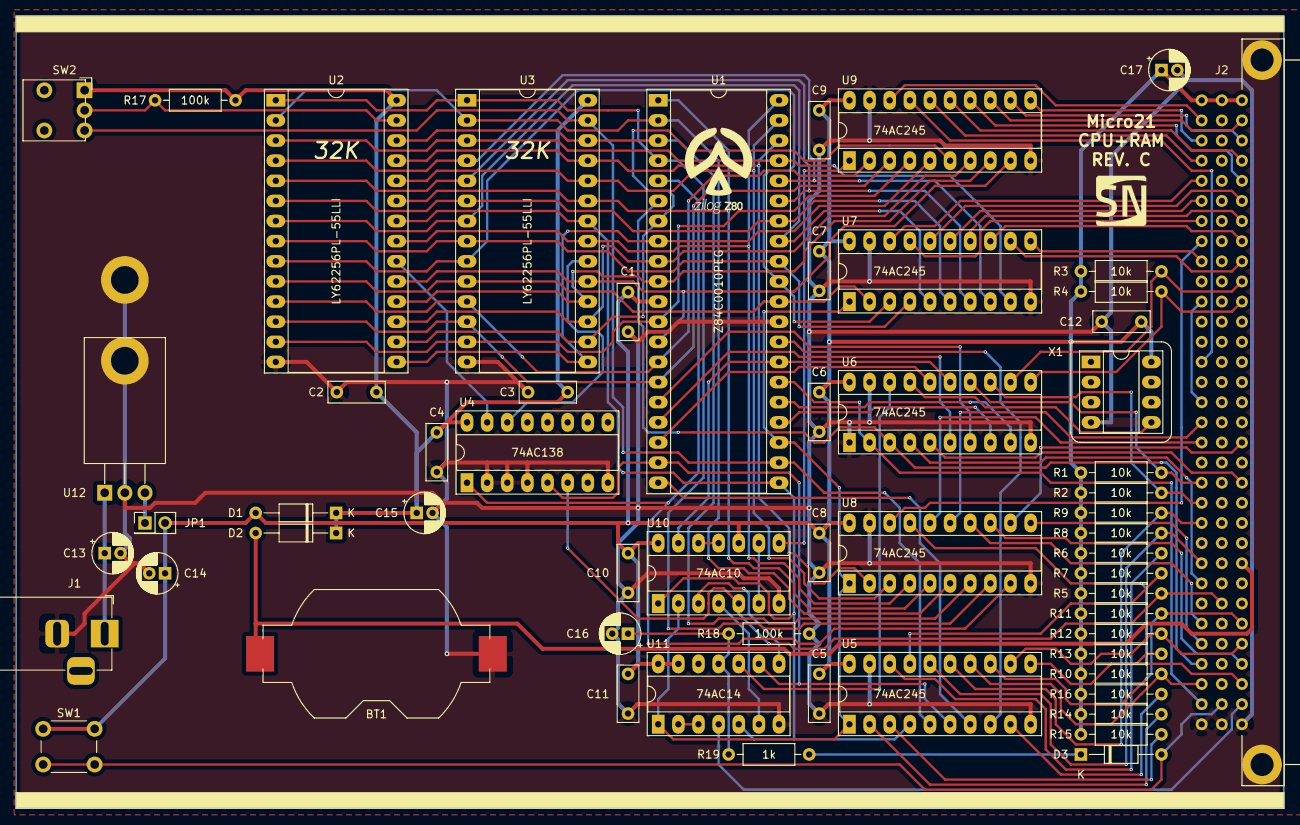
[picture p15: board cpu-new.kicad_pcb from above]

Board: 2 copper layers, 160.0 x 100.0 mm, 58 parts (0 on the bottom side), 102 nets.

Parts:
BT1: CR2032; BatteryHolder_Keystone_1058_1x2032
C1, C2, C3, C4, C5, C6, C7, C8, C9, C10, C11, C12: 100nF; C_Rect_L7.0mm_W2.5mm_P5.00mm
C13, C14: 10µF; CP_Radial_D5.0mm_P2.00mm
C15, C16, C17: 1µF; CP_Radial_D5.0mm_P2.00mm
D1, D2, D3: BAT46; D_DO-35_SOD27_P10.16mm_Horizontal
J1: Barrel_Jack; BarrelJack_Horizontal
J2: C96ABC; Socket_DIN41612-CaseC1-full-Male-96Pin-3rows
JP1: Jumper; PinHeader_2x01_P2.54mm_Vertical
R1, R2, R3, R4, R5, R6, R7, R8, R9, R10, R11, R12, R13, R14, R15, R16: 10k; R_Axial_DIN0207_L6.3mm_D2.5mm_P10.16mm_Horizontal
R17, R18: 100k; R_Axial_DIN0207_L6.3mm_D2.5mm_P10.16mm_Horizontal
R19: 1k; R_Axial_DIN0207_L6.3mm_D2.5mm_P10.16mm_Horizontal
SW1: SW_Push; SW_PUSH_6mm_H5mm
SW2: SW_SPDT; SW_Lever_1P2T_NKK_GW12LxH
U1: Z84C0010PEG; DIP-40_W15.24mm_Socket_LongPads
U2, U3: LY62256PL-55LLI; DIP-28_W15.24mm_Socket_LongPads
U4: 74AC138; DIP-16_W7.62mm_Socket_LongPads
U5, U6, U7, U8, U9: 74AC245; DIP-20_W7.62mm_Socket_LongPads
U10: 74AC10; DIP-14_W7.62mm_Socket_LongPads
U11: 74AC14; DIP-14_W7.62mm_Socket_LongPads
U12: L7805; TO-220-3_Horizontal_TabDown
X1: 10MHz; DIP-8_W7.62mm_Socket_LongPads

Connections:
+BATT: BT1.1, D2.2, J2.A24
A0: J2.C5, U7.18
A1: J2.C7, U7.17
A2: J2.A6, U7.16
A3: J2.C6, U7.15
A4: J2.A7, U7.14
A5: J2.A8, U7.13
A6: J2.A9, U7.12
A7: J2.C9, U7.11
A8: J2.C8, U8.18
A9: J2.A30, U8.17
A10: J2.C18, U8.16
A11: J2.C17, U8.15
A12: J2.C27, U8.14
A13: J2.A29, U8.13
A14: J2.A18, U8.12
A15: J2.C28, U8.11
CLK: J2.C29, U1.6, U6.3
D0: J2.C2, U9.18
D1: J2.C14, U9.17
D2: J2.C4, U9.16
D3: J2.A4, U9.15
D4: J2.A5, U9.14
D5: J2.A2, U9.13
D6: J2.A3, U9.12
D7: J2.C3, U9.11
GND: BT1.2, C1.2, C2.2, C3.2, C4.2, C5.2, C6.2, C7.2, C8.2, C9.2, C10.2, C11.2, C12.1, C13.2, C14.2, C15.2, C16.2, C17.2, J1.2, J2.A32, J2.B32, J2.C32, R18.1, U1.29, U2.14, U3.14, U4.2, U4.3, U4.4, U4.8, U5.10, U5.19, U6.1, U6.10, U6.19, U7.10, U7.19, U8.10, U8.19, U9.10, U9.19, U10.7, U11.7, U12.2, X1.4
unnamed: C13.1, J1.1, U12.1
unnamed: C16.1, R18.2, R19.2, U11.11
unnamed: D3.1, R19.1
unnamed: J2.C11, J2.C16
unnamed: JP1.1, U12.3
unnamed: R6.1, U5.18
unnamed: R7.1, U5.17
unnamed: R13.1, U5.11
unnamed: R14.1, U5.2
unnamed: R15.1, U5.3
unnamed: R16.1, U5.9
unnamed: R17.2, SW2.2, U2.27
unnamed: SW2.3, U1.22, U3.27, U5.5
unnamed: U1.1, U2.23, U3.23, U8.5
unnamed: U1.2, U2.2, U3.2, U8.6
unnamed: U1.3, U2.26, U3.26, U8.7
unnamed: U1.4, U2.1, U3.1, U8.8
unnamed: U1.5, U4.1, U8.9
unnamed: U1.7, U2.16, U3.16, U9.6
unnamed: U1.8, U2.15, U3.15, U9.5
unnamed: U1.9, U2.17, U3.17, U9.7
unnamed: U1.10, U2.18, U3.18, U9.8
unnamed: U1.12, U2.13, U3.13, U9.4
unnamed: U1.13, U2.19, U3.19, U9.9
unnamed: U1.14, U2.11, U3.11, U9.2
unnamed: U1.15, U2.12, U3.12, U9.3
unnamed: U1.16, U6.7
unnamed: U1.17, U6.6
unnamed: U1.18, U6.16
unnamed: U1.19, U4.5, U5.6, U11.9
unnamed: U1.20, U5.7
unnamed: U1.21, U2.22, U3.22, U5.4, U10.1, U11.5
unnamed: U1.23, U5.1, U7.1, U8.1, U10.2, U11.1
unnamed: U1.24, U6.8
unnamed: U1.25, U6.9
unnamed: U1.27, U6.15, U10.13
unnamed: U1.28, U5.8
unnamed: U1.30, U2.10, U3.10, U7.2
unnamed: U1.31, U2.9, U3.9, U7.3
unnamed: U1.32, U2.8, U3.8, U7.4
unnamed: U1.33, U2.7, U3.7, U7.5
unnamed: U1.34, U2.6, U3.6, U7.6
unnamed: U1.35, U2.5, U3.5, U7.7
unnamed: U1.36, U2.4, U3.4, U7.8
unnamed: U1.37, U2.3, U3.3, U7.9
unnamed: U1.38, U2.25, U3.25, U8.2
unnamed: U1.39, U2.24, U3.24, U8.3
unnamed: U1.40, U2.21, U3.21, U8.4
unnamed: U2.20, U4.15
unnamed: U3.20, U4.14
unnamed: U6.17, X1.5
unnamed: U10.3, U11.8
unnamed: U10.4, U11.6
unnamed: U10.6, U10.9
unnamed: U9.1, U10.8
unnamed: U10.11, U10.12
unnamed: U11.2, U11.3
unnamed: U6.18, U11.10
RESB: D3.2, J2.B31, SW1.2
VCC: C1.1, C5.1, C6.1, C7.1, C8.1, C9.1, C10.1, C11.1, C12.2, C14.1, C17.1, D1.2, J2.A1, J2.B1, J2.C1, JP1.2, R1.2, R2.2, R3.2, R4.2, R5.2, R6.2, R7.2, R8.2, R9.2, R10.2, R11.2, R12.2, R13.2, R14.2, R15.2, R16.2, SW1.1, U1.11, U5.20, U6.20, U7.20, U8.20, U9.20, U10.10, U10.14, U11.13, U11.14, X1.8
VMEM: C2.1, C3.1, C4.1, C15.1, D1.1, D2.1, R17.1, SW2.1, U2.28, U3.28, U4.16
~BUSACK: J2.A31, U11.4
~BUSRQ: J2.A11, R4.1, U6.11
~EXM: J2.B26, R5.1, U4.6, U10.5
~HALT: J2.C25, U6.4
~INT: J2.C21, R2.1, U6.13
~IORQ: J2.A27, R11.1, U5.13
~M1: J2.A20, U6.5
~MREQ: J2.C30, R10.1, U5.14
~NMI: J2.C20, R1.1, U6.14
~RD: J2.C24, R8.1, U5.16
~RESET: J2.C31, U1.26, U6.2
~RFSH: J2.A28, R12.1, U5.12
~WAIT: J2.A10, R3.1, U6.12
~WR: J2.C22, R9.1, U5.15

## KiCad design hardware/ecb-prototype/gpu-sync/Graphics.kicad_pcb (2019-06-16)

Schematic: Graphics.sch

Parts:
C1: CP_Small; CP_Radial_D5.0mm_P2.00mm
C2, C3, C4, C5, C6, C7, C8, C9, C10, C11, C12, C13, C14, C15, C16, C17, C18, C19, C20, C21, C22, C23, C24, C25: C_Small; C_Disc_D7.0mm_W2.5mm_P5.00mm
J1: C96ABC; Socket_DIN41612-CaseC1-full-Male-96Pin-3rows
J2: Conn_01x26_Male; IDC-Header_2x13_P2.54mm_Horizontal
R1, R2, R3, R4: 100k; R_Axial_DIN0207_L6.3mm_D2.5mm_P10.16mm_Horizontal
SW1: SW_Coded_SH-7050; Nidec_Copal_SH-7010C
U15: 74HC04; DIP-14_W7.62mm_Socket
U16, U17: 74HC109; DIP-16_W7.62mm_Socket
U18, U19, U20: 74AC573; DIP-20_W7.62mm_Socket
U29: 74HC688; DIP-20_W7.62mm_Socket
U30, U31: 74AC138; DIP-16_W7.62mm_Socket
U32, U33, U34: 74HC00; DIP-14_W7.62mm_Socket
X1: 25.175MHz; Oscillator_DIP-8_LargePads

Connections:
/BLANK: J2.18, U15.13, U34.11
/Column Counter/CE: U20.12; also elsewhere on the board
/Column Counter/D0: U19.19; also elsewhere on the board
/Column Counter/D1: U19.18; also elsewhere on the board
/Column Counter/D2: U19.17; also elsewhere on the board
/Column Counter/D3: U19.16; also elsewhere on the board
/Column Counter/D4: U19.15; also elsewhere on the board
/Column Counter/D5: U19.14; also elsewhere on the board
/Column Counter/D6: U19.13; also elsewhere on the board
/Column Counter/D7: U19.12; also elsewhere on the board
/Column Counter/D8: U20.19; also elsewhere on the board
/Column Counter/D9: U20.18; also elsewhere on the board
/HBLANK: J2.6; also elsewhere on the board
/HSYNC: J2.9, U16.10 (Q)
/HSYNC Generator/P0: J2.4; also elsewhere on the board
/PCLK: J2.2, U16.12 (C), U17.12 (C), X1.5; also elsewhere on the board
/Row Counter/D0: U18.19; also elsewhere on the board
/Row Counter/D1: U18.18; also elsewhere on the board
/Row Counter/D2: U18.17; also elsewhere on the board
/Row Counter/D3: U18.16; also elsewhere on the board
/Row Counter/D4: U18.15; also elsewhere on the board
/Row Counter/D5: U18.14; also elsewhere on the board
/Row Counter/D6: U18.13; also elsewhere on the board
/Row Counter/D7: U18.12; also elsewhere on the board
/Row Counter/D8: U20.15; also elsewhere on the board
/Row Counter/D9: U20.14; also elsewhere on the board
/TCC: J2.21, U15.2; also elsewhere on the board
/VBLANK: J2.12; also elsewhere on the board
/VSYNC: J2.15, U17.10 (Q)
/VSYNC Generator/P0: J2.26; also elsewhere on the board
/~BLANK: J2.19, U15.12
/~HBLANK: J2.7, U34.12; also elsewhere on the board
/~HSYNC: J2.10, U16.9 (~Q)
/~TCC: J2.22, U15.1; also elsewhere on the board
/~TCR: J2.24; also elsewhere on the board
/~VBLANK: J2.13, U34.13; also elsewhere on the board
/~VSYNC: J2.16, U17.9 (~Q)
A0: J1.C5, U30.1, U31.1
A1: J1.C7, U30.2, U31.2
A2: J1.A6, U30.3, U31.3
A3: J1.C6, U30.5, U31.6
A4: J1.A7, U29.2
A5: J1.A8, U29.4
A6: J1.A9, U29.6
A7: J1.C9, U29.8
D0: J1.C2, U18.2, U19.2, U20.2; also elsewhere on the board
D1: J1.C14, U18.3, U19.3, U20.3; also elsewhere on the board
D2: J1.C4, U18.4, U19.4, U20.4; also elsewhere on the board
D3: J1.A4, U18.5, U19.5, U20.5; also elsewhere on the board
D4: J1.A5, U18.6, U19.6, U20.6; also elsewhere on the board
D5: J1.A2, U18.7, U19.7, U20.7; also elsewhere on the board
D6: J1.A3, U18.8, U19.8, U20.8; also elsewhere on the board
D7: J1.C3, U18.9, U19.9, U20.9; also elsewhere on the board
GND: C1.2, C2.1, C3.1, C4.1, C5.1, C6.1, C7.1, C8.1, C9.1, C10.1, C11.1, C12.1, C13.1, C14.1, C15.1, C16.1, C17.1, C18.1, C19.1, C20.1, C21.1, C22.1, C23.1, C24.1, C25.1, J1.A32, J1.B32, J1.C32, J2.1, J2.3, J2.5, J2.8, J2.11, J2.14, J2.17, J2.20, J2.23, J2.25, R1.2, R2.2, R3.2, R4.2, U15.7, U16.8 (GND), U17.8 (GND), U18.1, U18.10, U19.1, U19.10, U20.1, U20.10, U29.1, U29.10, U29.12, U29.14, U29.15, U29.16, U29.17, U29.18, U30.8, U31.5, U31.8, U32.7, U33.7, U34.7, X1.4; also elsewhere on the board
unnamed: R1.1, SW1.1, U29.3
unnamed: R2.1, SW1.4, U29.7
unnamed: R3.1, SW1.2, U29.5
unnamed: R4.1, SW1.8, U29.9
unnamed 163: U16.13 (~K); also elsewhere on the board
unnamed 172: U15.9; also elsewhere on the board
unnamed 190: U15.11; also elsewhere on the board
unnamed 199: U17.13 (~K); also elsewhere on the board
unnamed 200: U15.3; also elsewhere on the board
unnamed 201: U15.4; also elsewhere on the board
unnamed 202: U15.5; also elsewhere on the board
unnamed: U15.6, U16.14 (J)
unnamed 204: U15.8; also elsewhere on the board
unnamed: U15.10, U17.14 (J)
unnamed: U18.11, U34.6
unnamed: U19.11, U34.3
unnamed: U20.11, U34.8
unnamed 213: U32.3; also elsewhere on the board
unnamed 222: U32.6; also elsewhere on the board
unnamed 231: U32.8; also elsewhere on the board
unnamed 240: U32.11; also elsewhere on the board
unnamed 241: U33.3; also elsewhere on the board
unnamed 242: U33.6; also elsewhere on the board
unnamed 243: U33.8; also elsewhere on the board
unnamed 244: U33.11; also elsewhere on the board
unnamed: U29.19, U30.4, U31.4
VCC: C1.1, C2.2, C3.2, C4.2, C5.2, C6.2, C7.2, C8.2, C9.2, C10.2, C11.2, C12.2, C13.2, C14.2, C15.2, C16.2, C17.2, C18.2, C19.2, C20.2, C21.2, C22.2, C23.2, C24.2, C25.2, J1.A1, J1.B1, J1.C1, SW1.C, U15.14, U16.11 (~S), U16.16 (VCC), U17.11 (~S), U17.16 (VCC), U18.20, U19.20, U20.20, U29.20, U30.6, U30.16, U31.16, U32.14, U33.14, U34.14, X1.8; also elsewhere on the board
~CS0: U30.15, U32.1
~CS1: U30.14, U32.4
~CS2: U30.13, U32.9
~CS3: U30.12, U32.12
~CS4: U30.11, U33.1
~CS5: U30.10, U33.4
~CS6: U30.9, U33.9
~CS7: U30.7, U33.12
~CS8: U31.15, U34.1
~CS9: U31.14, U34.4
~CS10: U31.13, U34.9
~IORQ: J1.A27, U29.11
~RESET: J1.C31, U16.15 (~R), U17.15 (~R), U32.2, U32.5, U32.10, U32.13, U33.2, U33.5, U33.10, U33.13, U34.2, U34.5, U34.10; also elsewhere on the board
~WR: J1.C22, U29.13

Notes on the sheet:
640x480@60Hz X0 = D9 X1 = 39 X2 = D4 X3 = 74 X4 = F6 X5 = 7E X6 = E4 X7 = E2 X8 = E1 X9 = F4 XA = 90

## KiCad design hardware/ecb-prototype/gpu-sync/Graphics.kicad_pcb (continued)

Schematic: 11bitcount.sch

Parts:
U1, U2, U3: 74AC161; DIP-16_W7.62mm_Socket

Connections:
/Column Counter/CE: U1.10; also elsewhere on the board
/Column Counter/D0: U1.3; also elsewhere on the board
/Column Counter/D1: U1.4; also elsewhere on the board
/Column Counter/D2: U1.5; also elsewhere on the board
/Column Counter/D3: U1.6; also elsewhere on the board
/Column Counter/D4: U2.3; also elsewhere on the board
/Column Counter/D5: U2.4; also elsewhere on the board
/Column Counter/D6: U2.5; also elsewhere on the board
/Column Counter/D7: U2.6; also elsewhere on the board
/Column Counter/D8: U3.3; also elsewhere on the board
/Column Counter/D9: U3.4; also elsewhere on the board
/Column Counter/Q10: U3.12
/HBLANK Generator/P0: U1.12; also elsewhere on the board
/HBLANK Generator/P1: U1.11; also elsewhere on the board
/HBLANK Generator/P2: U2.14; also elsewhere on the board
/HBLANK Generator/P3: U2.13; also elsewhere on the board
/HBLANK Generator/P4: U2.12; also elsewhere on the board
/HBLANK Generator/P5: U2.11; also elsewhere on the board
/HBLANK Generator/P6: U3.14; also elsewhere on the board
/HBLANK Generator/P7: U3.13; also elsewhere on the board
/HSYNC Generator/P0: U1.14; also elsewhere on the board
/HSYNC Generator/P1: U1.13; also elsewhere on the board
/PCLK: U1.2, U2.2, U3.2; also elsewhere on the board
/~TCC: U1.9, U2.9, U3.9, U3.11; also elsewhere on the board
GND: U1.8, U2.8, U3.8; also elsewhere on the board
unnamed: U1.15, U2.7, U3.7
unnamed: U2.15, U3.10
VCC: U1.7, U1.16, U2.10, U2.16, U3.5, U3.6, U3.16; also elsewhere on the board
~RESET: U1.1, U2.1, U3.1; also elsewhere on the board

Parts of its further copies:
U4, U5, U6: 74AC161; DIP-16_W7.62mm_Socket

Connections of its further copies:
/PCLK: U4.2, U5.2, U6.2; also elsewhere on the board
/Row Counter/D0: U4.3; also elsewhere on the board
/Row Counter/D1: U4.4; also elsewhere on the board
/Row Counter/D2: U4.5; also elsewhere on the board
/Row Counter/D3: U4.6; also elsewhere on the board
/Row Counter/D4: U5.3; also elsewhere on the board
/Row Counter/D5: U5.4; also elsewhere on the board
/Row Counter/D6: U5.5; also elsewhere on the board
/Row Counter/D7: U5.6; also elsewhere on the board
/Row Counter/D8: U6.3; also elsewhere on the board
/Row Counter/D9: U6.4; also elsewhere on the board
/Row Counter/Q10: U6.12
/TCC: U4.10; also elsewhere on the board
/VBLANK Generator/P0: U4.12; also elsewhere on the board
/VBLANK Generator/P1: U4.11; also elsewhere on the board
/VBLANK Generator/P2: U5.14; also elsewhere on the board
/VBLANK Generator/P3: U5.13; also elsewhere on the board
/VBLANK Generator/P4: U5.12; also elsewhere on the board
/VBLANK Generator/P5: U5.11; also elsewhere on the board
/VBLANK Generator/P6: U6.14; also elsewhere on the board
/VBLANK Generator/P7: U6.13; also elsewhere on the board
/VSYNC Generator/P0: U4.14; also elsewhere on the board
/VSYNC Generator/P1: U4.13; also elsewhere on the board
/~TCR: U4.9, U5.9, U6.9, U6.11; also elsewhere on the board
GND: U4.8, U5.8, U6.8; also elsewhere on the board
unnamed: U4.15, U5.7, U6.7
unnamed: U5.15, U6.10
VCC: U4.7, U4.16, U5.10, U5.16, U6.5, U6.6, U6.16; also elsewhere on the board
~RESET: U4.1, U5.1, U6.1; also elsewhere on the board

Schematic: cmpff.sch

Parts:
U7, U8: 74HC688; DIP-20_W7.62mm_Socket
U15: 74HC04; DIP-14_W7.62mm_Socket
U16: 74HC109; DIP-16_W7.62mm_Socket
U21, U22: 74AC573; DIP-20_W7.62mm_Socket
U33: 74HC00; DIP-14_W7.62mm_Socket

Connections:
/BLANK: U15.13; also elsewhere on the board
/HBLANK: U16.6 (Q); also elsewhere on the board
/HBLANK Generator/P0: U7.2, U8.2; also elsewhere on the board
/HBLANK Generator/P1: U7.4, U8.4; also elsewhere on the board
/HBLANK Generator/P2: U7.6, U8.6; also elsewhere on the board
/HBLANK Generator/P3: U7.8, U8.8; also elsewhere on the board
/HBLANK Generator/P4: U7.11, U8.11; also elsewhere on the board
/HBLANK Generator/P5: U7.13, U8.13; also elsewhere on the board
/HBLANK Generator/P6: U7.15, U8.15; also elsewhere on the board
/HBLANK Generator/P7: U7.17, U8.17; also elsewhere on the board
/HSYNC: U16.10 (Q); also elsewhere on the board
/PCLK: U16.4 (C), U16.12 (C); also elsewhere on the board
/TCC: U15.2; also elsewhere on the board
/~BLANK: U15.12; also elsewhere on the board
/~HBLANK: U16.7 (~Q); also elsewhere on the board
/~HSYNC: U16.9 (~Q); also elsewhere on the board
/~TCC: U15.1; also elsewhere on the board
D0: U21.2, U22.2; also elsewhere on the board
D1: U21.3, U22.3; also elsewhere on the board
D2: U21.4, U22.4; also elsewhere on the board
D3: U21.5, U22.5; also elsewhere on the board
D4: U21.6, U22.6; also elsewhere on the board
D5: U21.7, U22.7; also elsewhere on the board
D6: U21.8, U22.8; also elsewhere on the board
D7: U21.9, U22.9; also elsewhere on the board
GND: U7.1, U7.10, U8.1, U8.10, U15.7, U21.1, U21.10, U22.1, U22.10, U33.7; also elsewhere on the board
unnamed 163: U16.13 (~K); also elsewhere on the board
unnamed 172: U15.9; also elsewhere on the board
unnamed 190: U15.11; also elsewhere on the board
unnamed: U7.19, U15.3
unnamed: U15.4, U16.2 (J)
unnamed 202: U15.5; also elsewhere on the board
unnamed: U15.6, U16.14 (J)
unnamed 204: U15.8; also elsewhere on the board
unnamed 205: U15.10; also elsewhere on the board
unnamed: U8.19, U16.3 (~K)
unnamed 213: U21.11; also elsewhere on the board
unnamed: U7.18, U21.12
unnamed: U7.16, U21.13
unnamed: U7.14, U21.14
unnamed: U7.12, U21.15
unnamed: U7.9, U21.16
unnamed: U7.7, U21.17
unnamed: U7.5, U21.18
unnamed: U7.3, U21.19
unnamed 222: U22.11; also elsewhere on the board
unnamed: U8.18, U22.12
unnamed: U8.16, U22.13
unnamed: U8.14, U22.14
unnamed: U8.12, U22.15
unnamed: U8.9, U22.16
unnamed: U8.7, U22.17
unnamed: U8.5, U22.18
unnamed: U8.3, U22.19
unnamed 241: U33.3; also elsewhere on the board
unnamed 242: U33.6; also elsewhere on the board
unnamed 243: U33.8; also elsewhere on the board
unnamed 244: U33.11; also elsewhere on the board
VCC: U7.20, U8.20, U15.14, U16.5 (~S), U16.11 (~S), U21.20, U22.20, U33.14; also elsewhere on the board
~CS4: U33.1; also elsewhere on the board
~CS5: U33.4; also elsewhere on the board
~CS6: U33.9; also elsewhere on the board
~CS7: U33.12; also elsewhere on the board
~RESET: U16.1 (~R), U16.15 (~R), U33.2, U33.5, U33.10, U33.13; also elsewhere on the board

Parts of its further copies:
U9, U10, U11, U12, U13, U14: 74HC688; DIP-20_W7.62mm_Socket
U23, U24, U25, U26, U27, U28: 74AC573; DIP-20_W7.62mm_Socket

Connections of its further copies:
/HBLANK Generator/P0: U9.6, U10.6; also elsewhere on the board
/HBLANK Generator/P1: U9.8, U10.8; also elsewhere on the board
/HBLANK Generator/P2: U9.11, U10.11; also elsewhere on the board
/HBLANK Generator/P3: U9.13, U10.13; also elsewhere on the board
/HBLANK Generator/P4: U9.15, U10.15; also elsewhere on the board
/HBLANK Generator/P5: U9.17, U10.17; also elsewhere on the board
/HSYNC Generator/P0: U9.2, U10.2; also elsewhere on the board
/HSYNC Generator/P1: U9.4, U10.4; also elsewhere on the board
/VBLANK Generator/P0: U11.2, U12.2, U13.6, U14.6; also elsewhere on the board
/VBLANK Generator/P1: U11.4, U12.4, U13.8, U14.8; also elsewhere on the board
/VBLANK Generator/P2: U11.6, U12.6, U13.11, U14.11; also elsewhere on the board
/VBLANK Generator/P3: U11.8, U12.8, U13.13, U14.13; also elsewhere on the board
/VBLANK Generator/P4: U11.11, U12.11, U13.15, U14.15; also elsewhere on the board
/VBLANK Generator/P5: U11.13, U12.13, U13.17, U14.17; also elsewhere on the board
/VBLANK Generator/P6: U11.15, U12.15; also elsewhere on the board
/VBLANK Generator/P7: U11.17, U12.17; also elsewhere on the board
/VSYNC Generator/P0: U13.2, U14.2; also elsewhere on the board
/VSYNC Generator/P1: U13.4, U14.4; also elsewhere on the board
/~HBLANK: U9.1, U10.1; also elsewhere on the board
/~VBLANK: U13.1, U14.1; also elsewhere on the board
D0: U23.2, U24.2, U25.2, U26.2, U27.2, U28.2; also elsewhere on the board
D1: U23.3, U24.3, U25.3, U26.3, U27.3, U28.3; also elsewhere on the board
D2: U23.4, U24.4, U25.4, U26.4, U27.4, U28.4; also elsewhere on the board
D3: U23.5, U24.5, U25.5, U26.5, U27.5, U28.5; also elsewhere on the board
D4: U23.6, U24.6, U25.6, U26.6, U27.6, U28.6; also elsewhere on the board
D5: U23.7, U24.7, U25.7, U26.7, U27.7, U28.7; also elsewhere on the board
D6: U23.8, U24.8, U25.8, U26.8, U27.8, U28.8; also elsewhere on the board
D7: U23.9, U24.9, U25.9, U26.9, U27.9, U28.9; also elsewhere on the board
GND: U9.10, U10.10, U11.1, U11.10, U12.1, U12.10, U13.10, U14.10, U23.1, U23.10, U24.1, U24.10, U25.1, U25.10, U26.1, U26.10, U27.1, U27.10, U28.1, U28.10; also elsewhere on the board
unnamed: U10.3, U24.19
unnamed: U10.5, U24.18
unnamed: U10.7, U24.17
unnamed: U10.9, U24.16
unnamed: U10.12, U24.15
unnamed: U10.14, U24.14
unnamed: U10.16, U24.13
unnamed: U10.18, U24.12
unnamed 163: U10.19; also elsewhere on the board
unnamed: U11.3, U25.19
unnamed: U11.5, U25.18
unnamed: U11.7, U25.17
unnamed: U11.9, U25.16
unnamed: U11.12, U25.15
unnamed: U11.14, U25.14
unnamed: U11.16, U25.13
unnamed: U11.18, U25.12
unnamed 172: U11.19; also elsewhere on the board
unnamed: U12.3, U26.19
unnamed: U12.5, U26.18
unnamed: U12.7, U26.17
unnamed: U12.9, U26.16
unnamed: U12.12, U26.15
unnamed: U12.14, U26.14
unnamed: U12.16, U26.13
unnamed: U12.18, U26.12
unnamed 181: U12.19; also elsewhere on the board
unnamed: U13.3, U27.19
unnamed: U13.5, U27.18
unnamed: U13.7, U27.17
unnamed: U13.9, U27.16
unnamed: U13.12, U27.15
unnamed: U13.14, U27.14
unnamed: U13.16, U27.13
unnamed: U13.18, U27.12
unnamed 190: U13.19; also elsewhere on the board
unnamed: U14.3, U28.19
unnamed: U14.5, U28.18
unnamed: U14.7, U28.17
unnamed: U14.9, U28.16
unnamed: U14.12, U28.15
unnamed: U14.14, U28.14
unnamed: U14.16, U28.13
unnamed: U14.18, U28.12
unnamed 199: U14.19; also elsewhere on the board
unnamed 202: U9.19; also elsewhere on the board
unnamed 231: U23.11; also elsewhere on the board
unnamed: U9.18, U23.12
unnamed: U9.16, U23.13
unnamed: U9.14, U23.14
unnamed: U9.12, U23.15
unnamed: U9.9, U23.16
unnamed: U9.7, U23.17
unnamed: U9.5, U23.18
unnamed: U9.3, U23.19
unnamed 240: U24.11; also elsewhere on the board
unnamed 241: U25.11; also elsewhere on the board
unnamed 242: U26.11; also elsewhere on the board
unnamed 243: U27.11; also elsewhere on the board
unnamed 244: U28.11; also elsewhere on the board
VCC: U9.20, U10.20, U11.20, U12.20, U13.20, U14.20, U23.20, U24.20, U25.20, U26.20, U27.20, U28.20; also elsewhere on the board

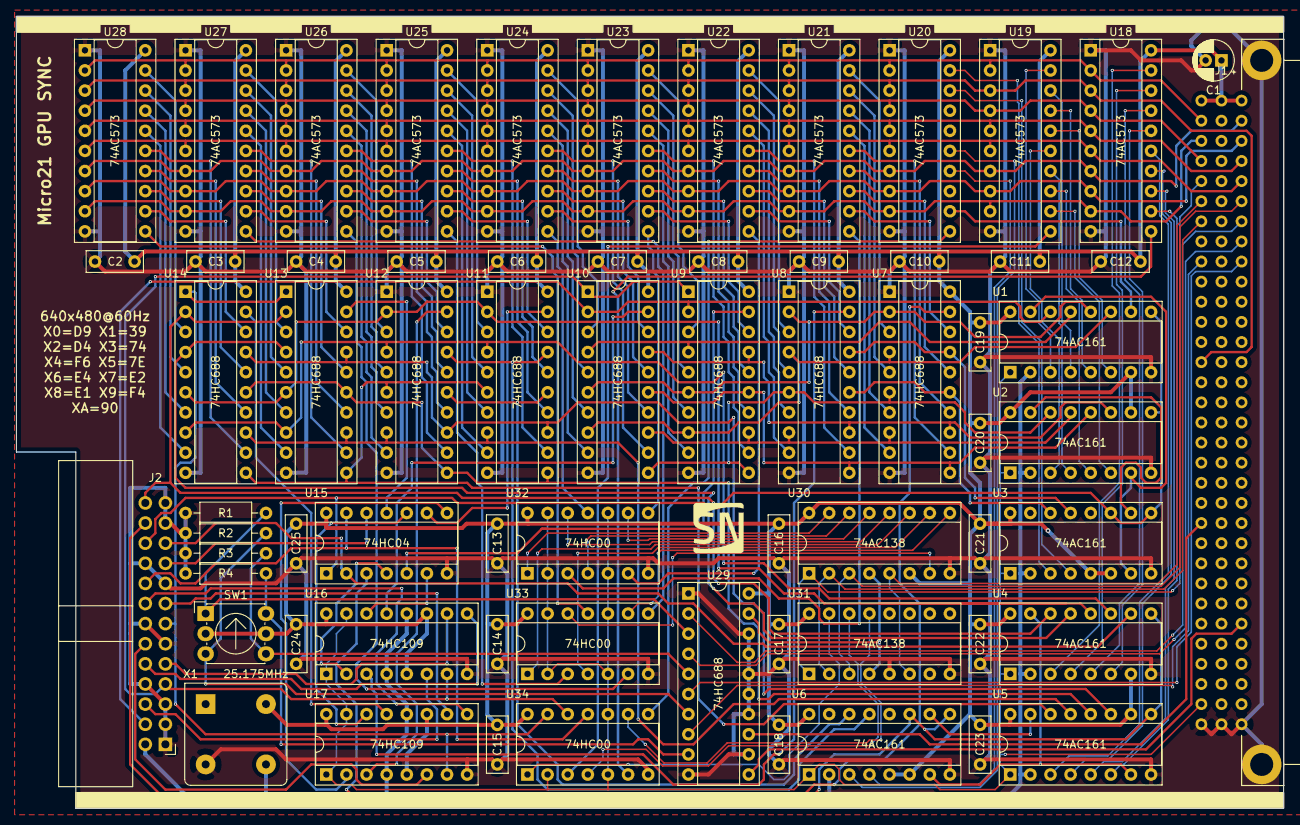
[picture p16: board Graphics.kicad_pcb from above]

Board: 2 copper layers, 160.0 x 100.0 mm, 67 parts (0 on the bottom side), 183 nets.

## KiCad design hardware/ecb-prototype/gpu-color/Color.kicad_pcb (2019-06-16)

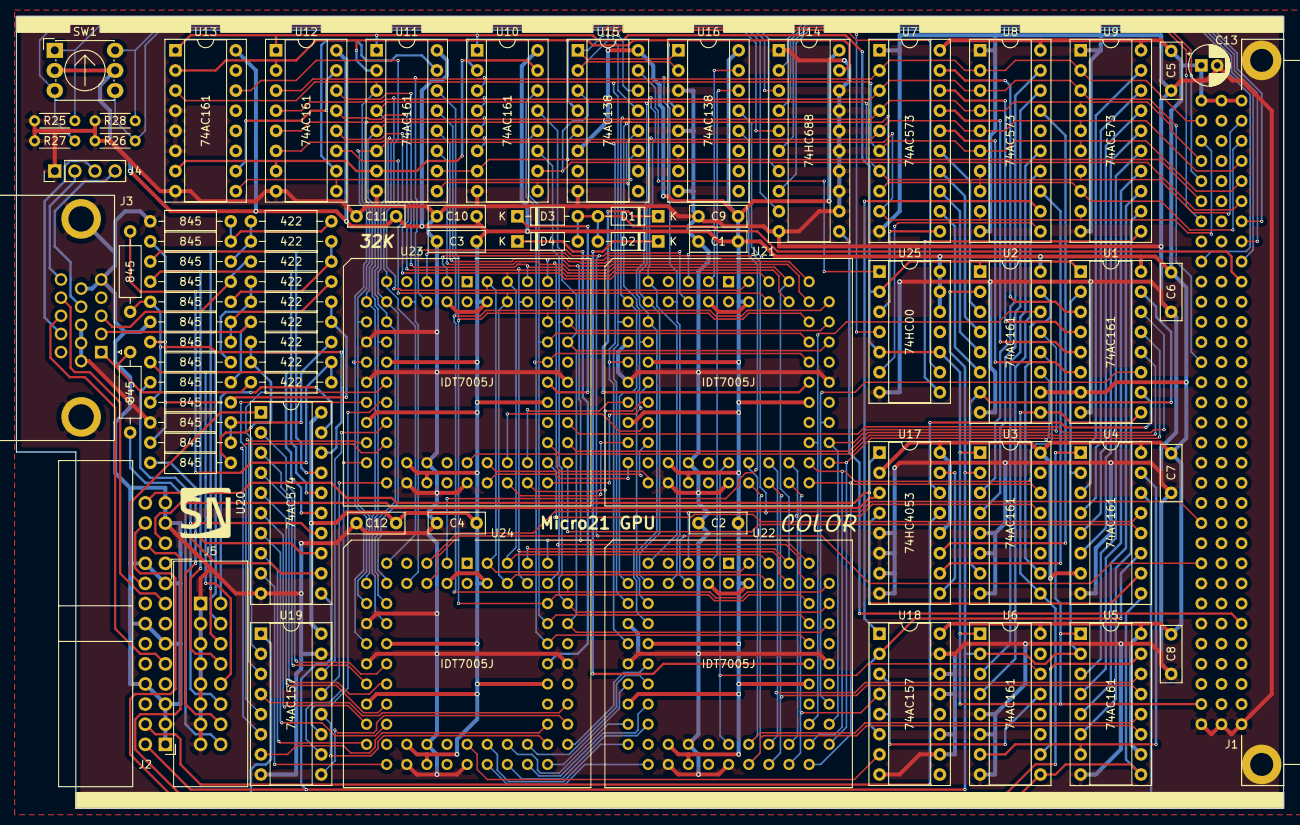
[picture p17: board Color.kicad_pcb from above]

Board: 2 copper layers, 160.0 x 100.0 mm, 76 parts (0 on the bottom side), 180 nets.

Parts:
C1, C2, C3, C4, C5, C6, C7, C8, C9, C10, C11, C12: C_Small; C_Rect_L7.0mm_W2.5mm_P5.00mm
C13: CP; CP_Radial_D5.0mm_P2.00mm
D1, D2, D3, D4: BAT46; D_DO-35_SOD27_P7.62mm_Horizontal
J1: C96ABC; Socket_DIN41612-CaseC1-full-Male-96Pin-3rows
J2: Conn_01x26_Male; IDC-Header_2x13_P2.54mm_Horizontal
J3: VGA; DSUB-15-HD_Female_Horizontal_P2.29x1.98mm_EdgePinOffset3.03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
J4: I2C; PinHeader_1x04_P2.54mm_Vertical
J5: Conn_02x08_Odd_Even; IDC-Header_2x08_P2.54mm_Vertical
R1, R2, R4, R6, R8, R9, R10, R12, R14, R16, R17, R18, R20, R22, R24: 845; R_Axial_DIN0207_L6.3mm_D2.5mm_P10.16mm_Horizontal
R3, R5, R7, R11, R13, R15, R19, R21, R23: 422; R_Axial_DIN0207_L6.3mm_D2.5mm_P10.16mm_Horizontal
R25, R26, R27, R28: 100k; R_Axial_DIN0204_L3.6mm_D1.6mm_P5.08mm_Horizontal
SW1: SW_Coded_SH-7050; Nidec_Copal_SH-7010C
U1, U2, U3, U4, U5, U6, U10, U11, U12, U13: 74AC161; DIP-16_W7.62mm_Socket
U7, U8, U9: 74AC573; DIP-20_W7.62mm_Socket
U14: 74HC688; DIP-20_W7.62mm_Socket
U15, U16: 74AC138; DIP-16_W7.62mm_Socket
U17: 74HC4053; DIP-16_W7.62mm_Socket
U18, U19: 74AC157; DIP-16_W7.62mm_Socket
U20: 74AC574; DIP-20_W7.62mm_Socket
U21, U22, U23, U24: IDT7005J; PLCC-68_THT-Socket
U25: 74HC00; DIP-14_W7.62mm_Socket

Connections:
/B: J3.3, R7.2, R8.2
/B0: J5.6, R4.1, U20.17
/B1: J5.8, R8.1, U20.16
/Color Table/A0: U1.11, U21.48, U22.48
/Color Table/A1: U2.14, U21.47, U22.47
/Color Table/A2: U2.13, U21.46, U22.46
/Color Table/A3: U2.12, U21.45, U22.45
/Color Table/A4: U2.11, U21.44, U22.44
/Color Table/A5: U3.14, U21.43, U22.43
/Color Table/A6: U3.13, U21.42, U22.42
/Color Table/A7: U18.4, U21.41, U22.41
/Color Table/A8: U5.14, U21.40, U22.40
/Color Table/A9: U5.13, U21.39, U22.39
/Color Table/A10: U5.12, U21.38, U22.38
/Color Table/A11: U5.11, U21.37, U22.37
/Color Table/A12: U6.14, U21.36, U22.36
/Column Counter/CE: U1.10, U17.14
/Column Counter/D0: U1.3, U7.19
/Column Counter/D1: U1.4, U7.18
/Column Counter/D2: U1.5, U7.17
/Column Counter/D3: U1.6, U7.16
/Column Counter/D4: U2.3, U7.15
/Column Counter/D5: U2.4, U7.14
/Column Counter/D6: U2.5, U7.13
/Column Counter/D7: U2.6, U7.12
/Column Counter/D8: U3.3, U8.19
/Column Counter/D9: U3.4, U8.18
/G: J3.2, R15.2, R16.2
/G0: J5.10, R12.1, U20.15
/G1: J5.12, R16.1, U20.14
/I0: J5.2, R2.1, R10.1, R18.1, U20.19
/I1: J5.4, R6.1, R14.1, R22.1, U20.18
/Palette Table/A0: U19.4, U24.48
/Palette Table/A1: U19.7, U24.47
/Palette Table/A2: U19.9, U24.46
/Palette Table/A3: U19.12, U24.45
/Palette Table/A4: U22.19, U24.44
/Palette Table/A5: U22.20, U24.43
/Palette Table/A6: U22.21, U24.42
/Palette Table/A7: U22.23, U24.41
/Palette Table/A8: U22.24, U24.40
/Palette Table/A9: U22.25, U24.39
/Palette Table/A10: U22.26, U24.38
/Palette Table/A11: U22.27, U24.37
/Palette Table/A12: U18.7, U24.36
/Palette Table/Q0: U20.2, U24.19
/Palette Table/Q1: U20.3, U24.20
/Palette Table/Q2: U20.4, U24.21
/Palette Table/Q3: U20.5, U24.23
/Palette Table/Q4: U20.6, U24.24
/Palette Table/Q5: U20.7, U24.25
/Palette Table/Q6: U20.8, U24.26
/Palette Table/Q7: U20.9, U24.27
/Pattern Table/A0: U1.14, U23.48
/Pattern Table/A1: U1.13, U23.47
/Pattern Table/A2: U1.12, U23.46
/Pattern Table/A3: U4.13, U23.45
/Pattern Table/A4: U4.12, U23.44
/Pattern Table/A5: U21.19, U23.43
/Pattern Table/A6: U21.20, U23.42
/Pattern Table/A7: U21.21, U23.41
/Pattern Table/A8: U21.23, U23.40
/Pattern Table/A9: U21.24, U23.39
/Pattern Table/A10: U21.25, U23.38
/Pattern Table/A11: U21.26, U23.37
/Pattern Table/A12: U21.27, U23.36
/Pattern Table/Q0: U19.2, U23.19
/Pattern Table/Q1: U19.5, U23.20
/Pattern Table/Q2: U19.11, U23.21
/Pattern Table/Q3: U19.14, U23.23
/Pattern Table/Q4: U19.3, U23.24
/Pattern Table/Q5: U19.6, U23.25
/Pattern Table/Q6: U19.10, U23.26
/Pattern Table/Q7: U19.13, U23.27
/R: J3.1, R23.2, R24.2
/R0: J5.14, R20.1, U20.13
/R1: J5.16, R24.1, U20.12
/Row Counter/CE: U4.10, U17.4
/Row Counter/D0: U4.3, U9.19
/Row Counter/D1: U4.4, U9.18
/Row Counter/D2: U4.5, U9.17
/Row Counter/D3: U4.6, U9.16
/Row Counter/D4: U5.3, U9.15
/Row Counter/D5: U5.4, U9.14
/Row Counter/D6: U5.5, U9.13
/Row Counter/D7: U5.6, U9.12
/Row Counter/D8: U6.3, U8.15
/Row Counter/D9: U6.4, U8.14
/Row Counter/Q0: U4.14, U19.1
/Row Counter/Q3: U4.11, U18.2, U18.6
/Row Counter/Q9: U6.13, U18.3, U18.5
A0: J1.C5, U15.1, U16.1
A1: J1.C7, U15.2, U16.2
A2: J1.A6, U10.10, U15.3
A3: J1.C6, U10.7, U11.10, U15.5, U16.6
A4: J1.A7, U14.2
A5: J1.A8, U14.4
A6: J1.A9, U14.6
A7: J1.C9, U14.8
AC0: U10.14, U21.55, U22.55, U23.55, U24.55
AC1: U10.13, U21.56, U22.56, U23.56, U24.56
AC2: U10.12, U21.57, U22.57, U23.57, U24.57
AC3: U10.11, U21.58, U22.58, U23.58, U24.58
AC4: U11.14, U21.59, U22.59, U23.59, U24.59
AC5: U11.13, U21.60, U22.60, U23.60, U24.60
AC6: U11.12, U21.61, U22.61, U23.61, U24.61
AC7: U11.11, U21.62, U22.62, U23.62, U24.62
AC8: U12.14, U21.63, U22.63, U23.63, U24.63
AC9: U12.13, U21.64, U22.64, U23.64, U24.64
AC10: U12.12, U21.65, U22.65, U23.65, U24.65
AC11: U12.11, U21.66, U22.66, U23.66, U24.66
AC12: U13.14, U21.67, U22.67, U23.67, U24.67
BLANK: J2.18, U20.1
D0: J1.C2, U7.2, U8.2, U9.2, U10.3, U12.3, U21.8, U22.8, U23.8, U24.8
D1: J1.C14, U7.3, U8.3, U9.3, U10.4, U12.4, U21.9, U22.9, U23.9, U24.9
D2: J1.C4, U7.4, U8.4, U9.4, U10.5, U12.5, U21.10, U22.10, U23.10, U24.10
D3: J1.A4, U7.5, U8.5, U9.5, U10.6, U12.6, U21.11, U22.11, U23.11, U24.11
D4: J1.A5, U7.6, U8.6, U9.6, U11.3, U13.3, U21.12, U22.12, U23.12, U24.12
D5: J1.A2, U7.7, U8.7, U9.7, U11.4, U21.13, U22.13, U23.13, U24.13
D6: J1.A3, U7.8, U8.8, U9.8, U11.5, U21.15, U22.15, U23.15, U24.15
D7: J1.C3, U7.9, U8.9, U9.9, U11.6, U21.16, U22.16, U23.16, U24.16
GND: C1.1, C2.1, C3.1, C4.1, C5.1, C6.1, C7.1, C8.1, C9.1, C10.1, C11.1, C12.1, C13.2, J1.A32, J1.B32, J1.C32, J2.1, J2.3, J2.5, J2.8, J2.11, J2.14, J2.17, J2.20, J2.23, J2.25, J3.0, J3.5, J3.6, J3.7, J3.8, J3.10, J4.1, J5.1, J5.3, J5.5, J5.7, J5.9, J5.11, J5.13, J5.15, R1.1, R9.1, R17.1, R25.2, R26.2, R27.2, R28.2, U1.8, U2.8, U3.5, U3.6, U3.8, U4.8, U5.8, U6.5, U6.6, U6.8, U7.1, U7.10, U8.1, U8.10, U9.1, U9.10, U10.8, U11.8, U12.8, U13.4, U13.5, U13.6, U13.8, U14.1, U14.10, U14.12, U14.13, U14.14, U14.15, U14.16, U14.17, U14.18, U15.8, U16.3, U16.5, U16.8, U17.5, U17.6, U17.7, U17.8, U18.8, U18.10, U18.11, U18.13, U18.14, U18.15, U19.8, U19.15, U20.10, U21.14, U21.18, U21.29, U21.32, U21.35, U21.52, U22.14, U22.18, U22.29, U22.32, U22.35, U22.52, U23.14, U23.18, U23.29, U23.32, U23.35, U23.52, U24.14, U24.18, U24.29, U24.32, U24.35, U24.52, U25.7
HSYNC: J2.9, J3.13
unnamed: D1.1, U21.53
unnamed: D2.1, U22.53
unnamed: D3.1, U23.53
unnamed: D4.1, U24.53
unnamed: J3.9, J4.4
unnamed: R1.2, R2.2, R3.1
unnamed: R3.2, R4.2, R5.1
unnamed: R5.2, R6.2, R7.1
unnamed: R9.2, R10.2, R11.1
unnamed: R11.2, R12.2, R13.1
unnamed: R13.2, R14.2, R15.1
unnamed: R17.2, R18.2, R19.1
unnamed: R19.2, R20.2, R21.1
unnamed: R21.2, R22.2, R23.1
unnamed: R25.1, SW1.1, U14.3
unnamed: R26.1, SW1.2, U14.5
unnamed: R27.1, SW1.4, U14.7
unnamed: R28.1, SW1.8, U14.9
unnamed: U1.15, U2.7, U3.7
unnamed: U2.15, U3.10
unnamed: U4.15, U5.7, U6.7
unnamed: U5.15, U6.10
unnamed: U10.2, U11.2, U12.2, U13.2, U14.19, U15.4, U16.4
unnamed: U10.15, U11.7, U12.7, U13.7
unnamed: U11.15, U12.10
unnamed: U12.15, U13.10
unnamed: U8.13, U17.10
unnamed: U8.17, U17.11
unnamed: U17.9, U17.15
unnamed: U8.12, U18.1
unnamed: U7.11, U25.3
unnamed: U8.11, U25.6
unnamed: U9.11, U25.8
ODDCOL: J2.4, U17.13
ODDROW: J2.26, U17.1
PCLK: J2.2, U1.2, U2.2, U3.2, U4.2, U5.2, U6.2, U20.11
SCL: J3.15, J4.2
SDA: J3.12, J4.3
TCC: J2.21, U17.3
VCC: C1.2, C2.2, C3.2, C4.2, C5.2, C6.2, C7.2, C8.2, C9.2, C10.2, C11.2, C12.2, C13.1, J1.A1, J1.B1, J1.C1, SW1.C, U1.7, U1.16, U2.10, U2.16, U3.16, U4.7, U4.16, U5.10, U5.16, U6.16, U7.20, U8.20, U9.20, U10.16, U11.16, U12.16, U13.16, U14.20, U15.6, U15.16, U16.16, U17.2, U17.12, U17.16, U18.16, U19.16, U20.20, U21.4, U21.17, U21.22, U21.30, U21.31, U21.51, U21.68, U22.4, U22.17, U22.22, U22.30, U22.31, U22.51, U22.68, U23.4, U23.17, U23.22, U23.30, U23.31, U23.51, U23.68, U24.4, U24.17, U24.22, U24.30, U24.31, U24.51, U24.68, U25.12, U25.13, U25.14
VSYNC: J2.15, J3.14
~CS0: U15.15, U25.1
~CS1: U15.14, U25.9
~CS2: U15.13, U25.4
~CS3: U10.9, U11.9, U15.12
~CS4: U12.9, U13.9, U15.11
~CS8: U16.15, U21.3
~CS9: U16.14, U22.3
~CS10: U16.13, U23.3
~CS11: U16.12, U24.3
~IORQ: J1.A27, U14.11
~RD: J1.C24, U21.6, U22.6, U23.6, U24.6
~RESET: J1.C31, U1.1, U2.1, U3.1, U4.1, U5.1, U6.1, U10.1, U11.1, U12.1, U13.1, U25.2, U25.5, U25.10
~TCC: J2.22, U1.9, U2.9, U3.9
~TCR: J2.24, U4.9, U5.9, U6.9
~WAIT: D1.2, D2.2, D3.2, D4.2, J1.A10
~WR: J1.C22, U21.5, U22.5, U23.5, U24.5

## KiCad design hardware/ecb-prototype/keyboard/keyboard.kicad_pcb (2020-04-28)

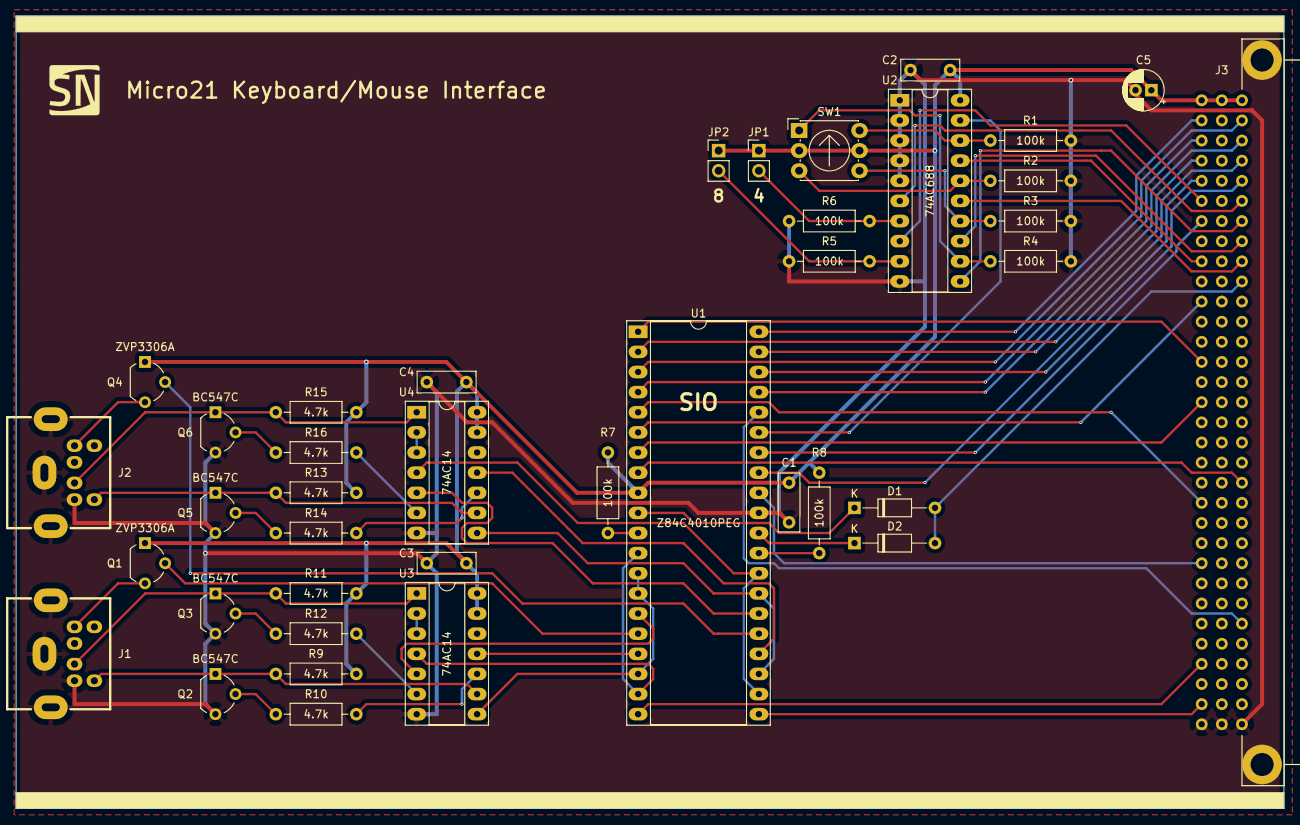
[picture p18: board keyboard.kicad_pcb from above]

Board: 2 copper layers, 160.0 x 100.0 mm, 39 parts (0 on the bottom side), 64 nets.

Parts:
C1, C2, C3, C4: 100nF; C_Rect_L7.2mm_W2.5mm_P5.00mm_FKS2_FKP2_MKS2_MKP2
C5: CP; CP_Radial_D5.0mm_P2.00mm
D1, D2: BAT46; D_DO-35_SOD27_P10.16mm_Horizontal
J1, J2: Mini-DIN-6; Mini_DIN_6
J3: C96ABC; Socket_DIN41612-CaseC1-full-Male-96Pin-3rows
JP1, JP2: Jumper_NO_Small; PinHeader_1x02_P2.54mm_Vertical
Q1, Q4: ZVP3306A; TO-92_Wide
Q2, Q3, Q5, Q6: BC547C; TO-92_Wide
R1, R2, R3, R4, R5, R6, R7, R8: 100k; R_Axial_DIN0207_L6.3mm_D2.5mm_P10.16mm_Horizontal
R9, R10, R11, R12, R13, R14, R15, R16: 4.7k; R_Axial_DIN0207_L6.3mm_D2.5mm_P10.16mm_Horizontal
SW1: SW_Coded_SH-7050; Nidec_Copal_SH-7010C
U1: Z84C4010PEG; DIP-40_W15.24mm_Socket_LongPads
U2: 74AC688; DIP-20_W7.62mm_Socket_LongPads
U3, U4: 74AC14; DIP-14_W7.62mm_Socket_LongPads

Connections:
/ps2a/CLKOUT: U1.17, U3.11
/ps2a/DATAIN: U1.12, U1.19, U3.4
/ps2a/DATAOUT: U1.15, U3.5
/ps2a/~CLKIN: U1.13, U1.14, U1.18, U3.8
/ps2a/~PWRON: Q1.2, U1.16
/ps2b/CLKOUT: U1.24, U4.11
/ps2b/DATAIN: U1.22, U1.28, U4.4
/ps2b/DATAOUT: U1.26, U4.5
/ps2b/~CLKIN: U1.23, U1.27, U4.8
/ps2b/~PWRON: Q4.2, U1.25
A0: J3.C5, U1.33
A1: J3.C7, U1.34
A2: J3.A6, U2.6
A3: J3.C6, U2.8
A4: J3.A7, U2.11
A5: J3.A8, U2.13
A6: J3.A9, U2.15
A7: J3.C9, U2.17
CLK: J3.C29, U1.20
D0: J3.C2, U1.40
D1: J3.C14, U1.1
D2: J3.C4, U1.39
D3: J3.A4, U1.2
D4: J3.A5, U1.38
D5: J3.A2, U1.3
D6: J3.A3, U1.37
D7: J3.C3, U1.4
GND: C1.1, C2.2, C3.1, C4.1, C5.2, J1.3, J2.3, J3.A32, J3.B32, J3.C32, Q2.3, Q3.3, Q5.3, Q6.3, R1.2, R2.2, R3.2, R4.2, R5.2, R6.2, U1.31, U2.1, U2.2, U2.3, U2.4, U2.5, U2.10, U3.7, U4.7
IEI: J3.C11, U1.6
IEO: J3.C16, U1.7
unnamed: D1.1, U1.10
unnamed: D2.1, U1.30
unnamed: J1.1, Q3.1, R11.1, U3.1
unnamed: J1.4, Q1.3
unnamed: J1.5, Q2.1, R9.1, U3.9
unnamed: J2.1, Q6.1, R15.1, U4.1
unnamed: J2.4, Q4.3
unnamed: J2.5, Q5.1, R13.1, U4.9
unnamed: JP1.2, R6.1, U2.7
unnamed: JP2.2, R5.1, U2.9
unnamed: Q2.2, R10.1
unnamed: Q3.2, R12.1
unnamed: Q5.2, R14.1
unnamed: Q6.2, R16.1
unnamed: R1.1, SW1.8, U2.18
unnamed: R2.1, SW1.4, U2.16
unnamed: R3.1, SW1.2, U2.14
unnamed: R4.1, SW1.1, U2.12
unnamed: R7.2, U1.11
unnamed: R8.2, U1.29
unnamed: R10.2, U3.10
unnamed: R12.2, U3.6
unnamed: R14.2, U4.10
unnamed: R16.2, U4.6
unnamed: U1.35, U2.19
unnamed: U3.2, U3.3
unnamed: U4.2, U4.3
VCC: C1.2, C2.1, C3.2, C4.2, C5.1, J3.A1, J3.B1, J3.C1, JP1.1, JP2.1, Q1.1, Q4.1, R7.1, R8.1, R9.2, R11.2, R13.2, R15.2, SW1.C, U1.9, U2.20, U3.13, U3.14, U4.13, U4.14
~INT: J3.C21, U1.5
~IORQ: J3.A27, U1.36
~M1: J3.A20, U1.8
~RD: J3.C24, U1.32
~RESET: J3.C31, U1.21
~WAIT: D1.2, D2.2, J3.A10

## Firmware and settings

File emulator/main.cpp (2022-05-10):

#include <iostream>
#include <emscripten.h>
#include <SDL2/SDL.h>
#include <SDL2/SDL_ttf.h>

#include <sys/mman.h>

#include "scene.hpp"

// 100%
//const int ticksPerFrame = 327673; // prime number
// 10%
//const int ticksPerFrame = 32771; // prime number
// 1%
//const int ticksPerFrame = 3271; // prime number
// 0.1%
const int ticksPerFrame = 331; // prime number
// 0.01%
//const int ticksPerFrame = 31; // prime number
// slowest
//const int ticksPerFrame = 1;

struct context
{
    bool initialized = false;
    SDL_Window *window;
    SDL_Renderer *renderer;
    Scene *scene;
    long frameCounter;
};

context ctx;

void init_fs()
{
    EM_ASM(
        FS.mkdir('/persistent_data');
        FS.mount(IDBFS, {}, '/persistent_data');
        Module.print("file sync started...");
        Module.syncdone = 0;
        FS.syncfs(true, function(err) {
                            assert(!err);
                            Module.print("file sync done.");
                            Module.syncdone = 1;
                        });
    );
}

void sync_fs(context *ctx)
{
    msync(ctx->scene->memory->buffer, ctx->scene->memory->memorySize, MS_SYNC);
    EM_ASM(
        if (Module.syncdone) {
            Module.syncdone = 0;
            //Module.print("file sync started...");
            FS.syncfs(false, function(err) {
                                 assert(!err);
                                 //Module.print("file sync done.");
                                 Module.syncdone = 1;
                             });
        }
    );
}

bool init_context(context *ctx)
{
    if (emscripten_run_script_int("Module.syncdone") != 1) return false;

    ctx->initialized = true;
    ctx->window = SDL_CreateWindow("LoopMicro Emulator",
                                   SDL_WINDOWPOS_UNDEFINED,
                                   SDL_WINDOWPOS_UNDEFINED,
                                   640, 480, SDL_WINDOW_RESIZABLE);
    ctx->renderer = SDL_CreateRenderer(ctx->window, -1,
                                       SDL_RENDERER_PRESENTVSYNC);
    ctx->scene = new Scene(ctx->window, ctx->renderer);

    return true;
}

void mainloop(void *arg)
{
    context *ctx = static_cast<context*>(arg);
    if (!ctx->initialized && !init_context(ctx)) return;

    // handle events on queue
    SDL_Event event;
    while (SDL_PollEvent(&event)) {
        ctx->scene->handleEvent(&event);
    }

    // run simulation
    for (int i = 0; i < ticksPerFrame; i++) {
        ctx->scene->tick();
    }

    // draw scene
    if (ctx->scene->render()) {
        SDL_RenderPresent(ctx->renderer);
    }

    if (ctx->frameCounter++ % 60 == 0) {
        sync_fs(ctx);
    }
}

int main()
{
    init_fs();

    SDL_Init(SDL_INIT_VIDEO);
    TTF_Init();

    ctx = {};

    // prevent main() from exiting
    const int simulate_infinite_loop = 1;
    // call the function as fast as the browser wants to render
    const int fps = -1;
    emscripten_set_main_loop_arg(mainloop, &ctx, fps, simulate_infinite_loop);
}

#include <emscripten/bind.h>

unsigned int peek(std::string source)
{
    if (source == "addr" ) return ctx.scene->addr  ->get_value();
    if (source == "data" ) return ctx.scene->data  ->get_value();
    if (source == "mreq" ) return ctx.scene->nMreq ->get_state() == SignalState::Low;
    if (source == "iorq" ) return ctx.scene->nIorq ->get_state() == SignalState::Low;
    if (source == "rd"   ) return ctx.scene->nRd   ->get_state() == SignalState::Low;
    if (source == "wr"   ) return ctx.scene->nWr   ->get_state() == SignalState::Low;
    if (source == "busak") return ctx.scene->nBusak->get_state() == SignalState::Low;
                           return -1;
}

void poke(std::string target, unsigned int value)
{
         if (target == "addr" ) ctx.scene->dipAddr->value = value;
    else if (target == "data" ) ctx.scene->dipData->value = value;
    else if (target == "mreq" ) ctx.scene->swMreq ->state = value;
    else if (target == "iorq" ) ctx.scene->swIorq ->state = value;
    else if (target == "rd"   ) ctx.scene->swRd   ->state = value;
    else if (target == "wr"   ) ctx.scene->swWr   ->state = value;
}

using namespace emscripten;

EMSCRIPTEN_BINDINGS(my_module) {
    function("peek", &peek);
    function("poke", &poke);
}

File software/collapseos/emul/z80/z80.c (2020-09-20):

// This unit has been copied from libz80 into Collapse OS and was slighly changed
/* =========================================================
 *  libz80 - Z80 emulation library
 * =========================================================
 *
 * (C) Gabriel Gambetta (gabriel.gambetta@gmail.com) 2000 - 2012
 *
 * Version 2.1.0
 *
 * ---------------------------------------------------------
 *
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
 *  You should have received a copy of the GNU General Public License
 *  along with this program; if not, write to the Free Software
 *  Foundation, Inc., 59 Temple Place - Suite 330, Boston, MA 02111-1307, USA.
 */

#include "z80.h"
#include "string.h"


#define BR (ctx->R1.br)
#define WR (ctx->R1.wr)

#define SETFLAG(F) setFlag(ctx, F)
#define RESFLAG(F) resFlag(ctx, F)
#define GETFLAG(F) getFlag(ctx, F)

#define VALFLAG(F,V) valFlag(ctx, F, V)


/* ---------------------------------------------------------
 *  Flag tricks
 * ---------------------------------------------------------
 *
 * To avoid repeating entries in the spec files, many operations that look similar are treated as special cases
 * of a more general operation.
 *
 * For example, ADD and ADC are similar in syntax and operation - the difference is that ADC takes the carry flag
 * into account.
 *
 * So we define a general operation doArithmetic(...) which accepts a boolean parameter specifying whether to do
 * a Carry-operation or not. Then, when we parse, we can say
 *
 * (ADD|ADC) ....
 *		doArithmetic(FLAG_FOR_%1)
 *
 * and everything works fine.
 *
 */

/* Flags for doIncDec() */
static const int ID_INC = 0;
static const int ID_DEC = 1;

/* Flags for enable / disable interrupts */
static const int IE_DI = 0;
static const int IE_EI = 1;

/* Flags for doSetRes() */
static const int SR_RES = 0;
static const int SR_SET = 1;

/* Flags for logical / arithmetic operations */
static const int IA_L = 0;
static const int IA_A = 1;

/* Flags for doArithmetic() - F1 = withCarry, F2 = isSub */
static const int F1_ADC = 1;
static const int F1_SBC = 1;
static const int F1_ADD = 0;
static const int F1_SUB = 0;

static const int F2_ADC = 0;
static const int F2_SBC = 1;
static const int F2_ADD = 0;
static const int F2_SUB = 1;

/* Increment or decrement R, preserving bit 7 */
#define INCR (ctx->R = (ctx->R & 0x80) | ((ctx->R + 1) & 0x7f))
#define DECR (ctx->R = (ctx->R & 0x80) | ((ctx->R - 1) & 0x7f))


/* ---------------------------------------------------------
 *  The opcode implementations
 * ---------------------------------------------------------
 */
#include "opcodes_decl.h"

typedef enum
{
	OP_NONE,
	OP_BYTE,
	OP_OFFSET,
	OP_WORD
} Z80OperandType;

typedef void (*Z80OpcodeFunc) (Z80Context* ctx);

struct Z80OpcodeEntry
{
	Z80OpcodeFunc func;

	int operand_type;
	char* format;

	struct Z80OpcodeTable* table;
};


struct Z80OpcodeTable
{
	int opcode_offset;
	struct Z80OpcodeEntry entries[256];
};


#include "opcodes_table.h"


/* ---------------------------------------------------------
 *  Data operations
 * ---------------------------------------------------------
 */
static void write8 (Z80Context* ctx, ushort addr, byte val)
{
	ctx->tstates += 3;
	ctx->memWrite(ctx->memParam, addr, val);
}


static void write16 (Z80Context* ctx, ushort addr, ushort val)
{
	write8(ctx, addr, val);
	write8(ctx, addr + 1, val >> 8);
}


static byte read8 (Z80Context* ctx, ushort addr)
{
	ctx->tstates += 3;
	return ctx->memRead(ctx->memParam, addr);
}


static ushort read16 (Z80Context* ctx, ushort addr)
{
	byte lsb = read8(ctx, addr);
	byte msb = read8(ctx, addr + 1);
	return msb << 8 | lsb;
}


static byte ioRead (Z80Context* ctx, ushort addr)
{
	ctx->tstates += 4;
	return ctx->ioRead(ctx->ioParam, addr);
}


static void ioWrite (Z80Context* ctx, ushort addr, byte val)
{
	ctx->tstates += 4;
	ctx->ioWrite(ctx->ioParam, addr, val);
}


/* ---------------------------------------------------------
 *  Flag operations
 * ---------------------------------------------------------
 */

/** Sets a flag */
static void setFlag(Z80Context* ctx, Z80Flags flag)
{
	BR.F |= flag;
}

/** Resets a flag */
static void resFlag(Z80Context* ctx, Z80Flags flag)
{
	BR.F &= ~flag;
}

/** Puts a value in a flag */
static void valFlag(Z80Context* ctx, Z80Flags flag, int val)
{
	if (val)
		SETFLAG(flag);
	else
		RESFLAG(flag);
}

/** Returns a flag */
static int getFlag(Z80Context* ctx, Z80Flags flag)
{
	return (BR.F & flag) != 0;
}


/* ---------------------------------------------------------
 *  Flag adjustments
 * ---------------------------------------------------------
 */

static int parityBit[256] = {
	1, 0, 0, 1, 0, 1, 1, 0, 0, 1, 1, 0, 1, 0, 0, 1,
	0, 1, 1, 0, 1, 0, 0, 1, 1, 0, 0, 1, 0, 1, 1, 0,
	0, 1, 1, 0, 1, 0, 0, 1, 1, 0, 0, 1, 0, 1, 1, 0,
	1, 0, 0, 1, 0, 1, 1, 0, 0, 1, 1, 0, 1, 0, 0, 1,
	0, 1, 1, 0, 1, 0, 0, 1, 1, 0, 0, 1, 0, 1, 1, 0,
	1, 0, 0, 1, 0, 1, 1, 0, 0, 1, 1, 0, 1, 0, 0, 1,
	1, 0, 0, 1, 0, 1, 1, 0, 0, 1, 1, 0, 1, 0, 0, 1,
	0, 1, 1, 0, 1, 0, 0, 1, 1, 0, 0, 1, 0, 1, 1, 0,
	0, 1, 1, 0, 1, 0, 0, 1, 1, 0, 0, 1, 0, 1, 1, 0,
	1, 0, 0, 1, 0, 1, 1, 0, 0, 1, 1, 0, 1, 0, 0, 1,
	1, 0, 0, 1, 0, 1, 1, 0, 0, 1, 1, 0, 1, 0, 0, 1,
	0, 1, 1, 0, 1, 0, 0, 1, 1, 0, 0, 1, 0, 1, 1, 0,
	1, 0, 0, 1, 0, 1, 1, 0, 0, 1, 1, 0, 1, 0, 0, 1,
	0, 1, 1, 0, 1, 0, 0, 1, 1, 0, 0, 1, 0, 1, 1, 0,
	0, 1, 1, 0, 1, 0, 0, 1, 1, 0, 0, 1, 0, 1, 1, 0,
	1, 0, 0, 1, 0, 1, 1, 0, 0, 1, 1, 0, 1, 0, 0, 1 };


static void adjustFlags (Z80Context* ctx, byte val)
{
	VALFLAG(F_5, (val & F_5) != 0);
	VALFLAG(F_3, (val & F_3) != 0);
}


static void adjustFlagSZP (Z80Context* ctx, byte val)
{
	VALFLAG(F_S, (val & 0x80) != 0);
	VALFLAG(F_Z, (val == 0));
	VALFLAG(F_PV, parityBit[val]);
}


/* Adjust flags after AND, OR, XOR */
static void adjustLogicFlag (Z80Context* ctx, int flagH)
{
    VALFLAG(F_S, (BR.A & 0x80) != 0);
    VALFLAG(F_Z, (BR.A == 0));
    VALFLAG(F_H, flagH);
    VALFLAG(F_N, 0);
    VALFLAG(F_C, 0);
    VALFLAG(F_PV, parityBit[BR.A]);

    adjustFlags(ctx, BR.A);
}


/* ---------------------------------------------------------
 *  Condition checks
 * ---------------------------------------------------------
 */

typedef enum
{
	C_,
	C_Z,
	C_NZ,
	C_C,
	C_NC,
	C_M,
	C_P,
	C_PE,
	C_PO
} Z80Condition;

static int condition(Z80Context* ctx, Z80Condition cond)
{
	if (cond == C_)
		return 1;

	if (cond == C_Z)
		return GETFLAG(F_Z);

	if (cond == C_NZ)
		return !GETFLAG(F_Z);

	if (cond == C_C)
		return GETFLAG(F_C);

	if (cond == C_NC)
		return !GETFLAG(F_C);

	if (cond == C_M)
		return GETFLAG(F_S);

	if (cond == C_P)
		return !GETFLAG(F_S);

	if (cond == C_PE)
		return GETFLAG(F_PV);

/*	if (cond == C_PO)*/
		return !GETFLAG(F_PV);
}


/* ---------------------------------------------------------
 *  Generic operations
 * ---------------------------------------------------------
 */


static int doComplement(byte v)
{
	if ((v & 0x80) == 0)
		return v;

	v = ~v;
	v &= 0x7F;
	v++;

	return -v;
}
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

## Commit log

2019-05-15 added memory board schematics
    [memory.kicad_pcb, memory.sch]
2019-05-15 generated memory board netlist
    [memory.kicad_pcb, memory.sch]
2019-05-16 add gpu sync generator board
    [11bitcount.sch, Graphics.kicad_pcb, Graphics.sch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]
2019-05-18 gpu sync board component placement
    [11bitcount.sch, Graphics.kicad_pcb, Graphics.sch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]
2019-05-20 gpu sync board routed
    [11bitcount.sch, Graphics.kicad_pcb, Graphics.sch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]
2019-05-20 layout memory
    [memory.kicad_pcb, memory.sch]
2019-05-25 add ledrom pcb files
    [8bytes.sch, AddrDecode.sch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]
2019-05-25 add gpu color pcb
    [10bitctr.sch, 8kmem.sch, Color.kicad_pcb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]
2019-05-25 add cpu pcb
    [z80.kicad_pcb, z80.sch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]
2019-05-25 add monitor pcb
    [7seg.sch, 7segs.sch, 850030567.stp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]
2019-05-25 leave space for guide rails
    [Graphics.kicad_pcb]
2019-05-25 gpu color pcb schematic finalized, component placement idea
    [10bitctr.sch, 8kmem.sch, Color.kicad_pcb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]
2019-05-26 component placement
    [10bitctr.sch, 8kmem.sch, Color.kicad_pcb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]
2019-05-27 gpu color pcb routing (wip)
    [10bitctr.sch, 8kmem.sch, Color.kicad_pcb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]
2019-06-02 gpu color pcb routing (almost done)
    [Color.kicad_pcb]
2019-06-06 gpu color pcb routing
    [Color.kicad_pcb]
2019-06-10 add 3d shapes
    [Graphics.kicad_pcb]
2019-06-10 backplane (wip)
    [backplane.kicad_pcb, backplane.sch]
2019-06-10 GPU color: add connector for internal screen; add text and logo
    [10bitctr.sch, 8kmem.sch, Color.kicad_pcb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]
2019-06-15 routed backplane
    [backplane.kicad_pcb, backplane.sch]
2019-06-15 add 3d models
    [Color.kicad_pcb]
2019-06-15 add reset button, minor tweaks
    [backplane.kicad_pcb, backplane.sch]
2019-06-16 final pcb layout tweaks / production run
    [Color.kicad_pcb, Graphics.kicad_pcb, backplane.kicad_pcb]
2019-07-25 new cpu board schematic
    [cpu-new.kicad_pcb, cpu-new.sch]
2019-07-28 new cpu (+ram) board
    [cpu-new.kicad_pcb, cpu-new.sch]
2019-08-01 keyboard interface
    [keyboard.kicad_pcb, keyboard.sch, ps2.sch]
2019-08-01 minor adjustments
    [cpu-new.kicad_pcb, cpu-new.sch]
2019-09-17 new file
    [sd.kicad_pcb, sd.sch]
2019-09-20 memory card interface wip
    [sd.sch]
2019-09-26 pcb routing
    [sd.kicad_pcb, sd.sch]
2020-04-28 keyboard pcb
    [keyboard.kicad_pcb, keyboard.sch]
2020-08-21 reorganize project
    [10bitctr.sch, 11bitcount.sch, 7seg.sch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]
2020-08-25 add work in progress files
    [channel.sch, sd.kicad_pcb, sd.sch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]
2020-08-30 taskbar button input handler
2020-08-30 taskbar button toggle behavior
2020-10-19 app switching
2021-08-02 upgrade collapseos version, wip drivers rewrite
2021-08-04 keyboard driver works now
2021-08-14 sdc driver
2021-11-28 add toggle switch
2022-01-17 implement dip switch
2022-01-27 implement oscillator + LED POV effect
    [main.cpp]
2022-05-10 add JS bindings to emulator
    [main.cpp]

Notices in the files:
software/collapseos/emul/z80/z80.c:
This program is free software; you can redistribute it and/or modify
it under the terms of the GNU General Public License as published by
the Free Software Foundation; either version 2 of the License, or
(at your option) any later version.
